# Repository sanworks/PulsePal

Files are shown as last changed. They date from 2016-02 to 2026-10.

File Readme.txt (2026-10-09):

This is the Sanworks Pulse Pal repository, maintained by Sanworks LLC.

It is an improved version of the original Pulse Pal project:
https://www.frontiersin.org/journals/neuroengineering/articles/10.3389/fneng.2014.00043/full

Pulse Pal is an open source instrument, released into the public domain under the GNU public license version 3 (see LICENSE.txt).

IMPORTANT: This license means that you can build and modify the device for your own use and even release derivative works commercially, but all derivative versions of the software and hardware MUST remain open source under the GNU public license v3.

This repository contains:
-Firmware (written in Arduino)
-Software APIs in MATLAB, Python and C++
-Design files for the circuit board
-Design files for the enclosure

Documentation and bill of materials is provided online at:
https://sites.google.com/site/pulsepalwiki/

Code contributions are welcome! Please follow guidelines in CONTRIBUTING.md

Using Pulse Pal from Python or MATLAB: USING.md covers the device limits, the standard calls, recipes for common
experiments and pitfalls.

Developer documentation: AGENTS.md is the guide to this repository (for people and for AI coding agents),
and Firmware/PROTOCOL.md documents the USB serial protocol.

Preassembled Pulse Pals are available at:
https://sanworks.io

The online documentation contains:

-Ordering and assembly guide
-Installation guide
-Programming guides
-Parameter guide
-Serial interface documentation

Please contact us with any questions, bugs, and general feedback:
admin@sanworks.io

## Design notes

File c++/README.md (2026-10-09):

# Pulse Pal C++ class

A C++ interface for Pulse Pal 2 and Pulse Pal 3, running firmware v21 or v22, on Windows, macOS and Linux.

```cpp
#include "PulsePal.h"

PulsePal pulsePal;
if (!pulsePal.initialize("COM3")) {  // "/dev/cu.usbmodem14101" on macOS, "/dev/ttyACM0" on Linux
    return 1;
}
pulsePal.setPhase1Voltage(1, 5);       // 5V pulses on output channel 1
pulsePal.setPulseTrainDuration(1, 2);  // for 2 seconds
pulsePal.triggerChannel(1);
pulsePal.end();
```

[PulsePal.h](PulsePal.h) documents every method. [PulsePalExample.cpp](PulsePalExample.cpp) is a longer
example, and the serial protocol is described in [/Firmware/PROTOCOL.md](../Firmware/PROTOCOL.md).

The class uses [libserialport](https://sigrok.org/wiki/Libserialport) for the USB serial port. It is an actively
maintained, cross-platform C library from the sigrok project, packaged for Homebrew, Debian/Ubuntu, MSYS2 and
vcpkg, and licensed LGPL-3.0-or-later. The previous version of this class, built on openFrameworks' `ofSerial`, is
in [legacy/](legacy/). Use it for Pulse Pal 1.

## Building

You need CMake 3.14 or newer and a C++11 compiler. The build makes a static library, `pulsepal`, the example
program `PulsePalExample`, and the offline tests `test_protocol`.

### Windows 11

Install Visual Studio 2022 with the "Desktop development with C++" workload, which includes CMake and the Windows
SDK. Then, in a Developer PowerShell, from this folder:

```bash
cmake -S . -B build
cmake --build build --config Release
build\Release\PulsePalExample.exe COM3
```

The first `cmake` downloads libserialport 0.1.2 from sigrok.org, checks its SHA-256 hash, and builds it with the
project, so there is nothing else to install. (Or open this folder in Visual Studio with File > Open > Folder.)

Pulse Pal's port is listed in Device Manager under "Ports (COM & LPT)".

### macOS

```bash
brew install cmake pkg-config libserialport
cmake -S . -B build
cmake --build build
./build/PulsePalExample /dev/cu.usbmodem14101
```

Pulse Pal appears as `/dev/cu.usbmodem*`. List the candidates with `ls /dev/cu.usbmodem*`. Use the `cu.` device,
not `tty.`.

### Ubuntu

```bash
sudo apt install build-essential cmake pkg-config libserialport-dev
cmake -S . -B build
cmake --build build
./build/PulsePalExample /dev/ttyACM0
```

Pulse Pal appears as `/dev/ttyACM*`. To open it without `sudo`, add yourself to the `dialout` group once, then log
out and back in:

```bash
sudo usermod -aG dialout $USER
```

## Using the class in your project

With CMake, add this folder and link to `pulsepal`:

```cmake
add_subdirectory(path/to/PulsePal/c++ pulsepal)
target_link_libraries(your_app PRIVATE pulsepal)
```

Without CMake, compile `PulsePal.cpp` and `SerialPort.cpp` with your program, and link to libserialport. Only
`SerialPort.cpp` includes `libserialport.h`.

## Errors

Methods that send a command return `true` if it was sent and, for commands the device confirms, the device
confirmed it. They return `false`, and print the reason to `std::cerr`, if:

- the device is not connected,
- an argument is out of range for the connected device, in which case nothing is sent,
- or the device rejected the command, or did not reply within 2 seconds.

A device that stops replying is usually showing **COMM. FAILURE!** on its screen, after a command was cut short (a
faulty cable or hub, or a program that stopped mid-command). Click its joystick, and call `initialize()` again.

## Pulse Pal 3

- Custom pulse trains 1-4, with up to 10,000 pulses each (Pulse Pal 2: trains 1-2, 5,000 pulses).
- Param sync trigger mode: `setTriggerMode(channel, 3)`. While a trigger channel is in this mode,
  `syncAllParams()` stores the parameters on the device, and the next rising edge on that trigger channel applies
  them. This is how the next trial's parameters can be sent during the current trial. Only `syncAllParams()` is
  held back: every other method takes effect at once. See "Param sync mode" in
  [/Firmware/PROTOCOL.md](../Firmware/PROTOCOL.md).
- `getHardwareVersion()` returns 2 or 3.

## Changes from the legacy class

The methods and fields are the same as in [legacy/PulsePal.h](legacy/PulsePal.h), plus `getHardwareVersion()`.
These changed:

- Pulse Pal 1, and firmware older than v21, are not supported. Use the legacy class.
- Methods that sent a command now return `bool` instead of `void` (see [Errors](#errors)). `initialize()` also
  returns `bool`.
- `initialize()` now programs the device with the default parameters, as the MATLAB and Python classes do, so
  that the device and `currentOutputParams` agree.
- Out-of-range values are rejected, instead of silently limited. Voltages are -10 to 10 V. Times are 0 to
  9999.9999 s, the longest time the device's joystick menu shows, except phase durations, the inter-pulse interval
  and the pulse train duration, whose minimum is 0.0001 s: two timer cycles, the shortest pulse a trigger channel
  detects reliably. Custom pulse times must be multiples of 0.0001 s. These are the MATLAB and Python classes'
  limits, listed in "Value limits" in [/Firmware/PROTOCOL.md](../Firmware/PROTOCOL.md).
- Times are rounded to the nearest 50 µs timer cycle, and voltages to the nearest DAC code, as in the Python
  class. The legacy class truncated times, so e.g. a 0.0007 s phase was sent as 13 cycles (0.00065 s) instead of 14.
- The device's confirm bytes are read. The legacy class left them unread.
- Fixed: `setInterPulseInterval()` stored its value in `interPhaseInterval`; `currentInputParams` (the trigger
  modes) was uninitialized, so `syncAllParams()` could send any trigger mode; `setPulseTrainDelay()` could not set
  a delay of 0.
- `stdafx.h` and the Visual Studio `_tmain` entry point are no longer needed.

## Tests

`tests/test_protocol.cpp` checks the bytes the class sends, using a fake serial port, so it needs no Pulse Pal. It
compares the parameter messages (ops 92 and 73) with those sent by the Python class, byte for byte. Run it after
building:

```bash
ctest --test-dir build -C Release --output-on-failure
```

(`--test-dir` needs CMake 3.20. On older versions, run `ctest -C Release` from the `build` folder.)

Everything else needs a device. `PulsePalExample` calls every method on a connected Pulse Pal, and plays pulse
trains of up to ±10 V on all four output channels, so disconnect anything attached to the outputs first.

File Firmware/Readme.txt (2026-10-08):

This folder contains the Pulse Pal firmware. To load it onto a device you can either compile it
yourself with Arduino (https://www.arduino.cc/en/software/#ide), or use a firmware loader that
needs no Arduino setup.

Loading firmware without Arduino:

1. With Python: the firmware loader for all Sanworks devices, including Pulse Pal, at
   https://github.com/sanworks/Sanworks-FirmwareLoader
2. With MATLAB: the firmware loading tool in /MATLAB/FirmwareLoader/

Compiling it yourself: the board support and libraries must be installed first. They are listed
at the top of PulsePal3/PulsePal3.ino, and in the "Building" section of PulsePal3/AGENTS.md.

Folders and files:

/PulsePal3
The current firmware. It compiles for both Pulse Pal 2 (Arduino Due) and Pulse Pal 3 (Teensy 4.1),
selected with the HARDWARE_VERSION macro at the top of PulsePal3.ino. AGENTS.md in that folder has
the code map, build instructions and the rules to follow when changing the firmware.

/WavePal
Wave Pal: alternative firmware for Pulse Pal 3 (Teensy 4.1) that makes it a four channel waveform
player. Each output channel plays a waveform of up to 1 million samples, stored on the microSD card,
when it is triggered by TTL, by software or from the joystick. It is controlled with the Python class
pulsepal.WavePalDevice (/Python/PulsePal/pulsepal/wave_pal.py) or the MATLAB class in /MATLAB/@WavePalDevice.
PROTOCOL.md and AGENTS.md in that folder describe its USB protocol and code.

/SynthPal
Synth Pal: alternative firmware for Pulse Pal 3 (Teensy 4.1) that makes it a four channel waveform
synthesizer. Each output channel plays a sine, triangle, square or sawtooth wave, or steps to a fixed
voltage, with its own levels, play duration and ramps, when it is triggered by TTL, by software or
from the joystick. One frequency, 1 Hz to 20 kHz, applies to all four. It is controlled with the
Python class pulsepal.SynthPalDevice (/Python/PulsePal/pulsepal/synth_pal.py) or the MATLAB class in
/MATLAB/@SynthPalDevice.
PROTOCOL.md and AGENTS.md in that folder describe its USB protocol and code.

/Old
Archived firmware for earlier hardware and releases, kept for reference and no longer developed.

/tools
build_check.py compiles the firmware for both hardware versions, or Wave Pal or Synth Pal (--sketch).
It can also compare the compiled code with another git revision, function by function, to confirm that
an edit did not change behavior.

PROTOCOL.md
The USB serial protocol between the device and its Python, MATLAB and C++ clients: op codes,
parameter codes, replies and the settings file layout.

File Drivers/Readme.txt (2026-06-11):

Drivers are necessary only for Windows 7 and Windows XP.
If you are using a modern operating system, you can safely ignore this folder.

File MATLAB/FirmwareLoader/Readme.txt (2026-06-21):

**MATLAB Firmware Loader for Pulse Pal**

Usage:
1. Add this folder to the MATLAB path
2. At the MATLAB command prompt, run LoadPulsePalFirmware;

Firmware files in this folder begin with stable versions as of 1 July, 2026, and include more recent updates.
If you need an earlier firmware version, it must be installed manually. Installation instructions are here:
https://sites.google.com/site/pulsepalwiki/upgrading-firmware

Note: If Python is available on your system, a unified firmware loader for all Sanworks devices is provided at https://github.com/sanworks/Sanworks-FirmwareLoader

**Credits**
Note: Firmware updating for Pulse Pal v3 / Teensy 4.1  is powered by tycmd, an open source firmware loader application for Teensy.
More details at: https://github.com/Koromix/tytools

For Pulse Pal v2 / Arduino Due, firmware updating is powered by bossac.
More details at: https://github.com/shumatech/BOSSA

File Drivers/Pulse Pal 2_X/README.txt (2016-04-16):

The driver files in this folder are open source, and part of the Arduino program:

http://www.arduino.cc/

We supply these drivers for convenience, but we reccommend downloading the latest drivers from here:
https://www.arduino.cc/en/Guide/ArduinoDue#toc8

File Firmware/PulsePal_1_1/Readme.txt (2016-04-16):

Firmware Upload Instructions

The Pulse Pal firmware can be uploaded to Pulse Pal 1 device using Leaflabs Maple software.

1. Download Maple from:
http://docs.leaflabs.com/docs.leaflabs.com/index.html
and install it on your system. 

On Windows Vista, 7, 8 and 10, you will need to install the driver from here:
https://github.com/rogerclarkmelbourne/Arduino_STM32/tree/master/drivers/win

2. Launch Maple

3. Select: File > Open and choose /PulsePal/Firmware/PulsePal_X_X/PulsePal_X_X.pde

4. Select Tools > Board > Leaflabs Maple r3+ To Flash

5. Select Tools > Port > (whichever port appears when you connect Pulse Pal, and disappears when it is disconnected)

6. Press "Upload" - the right-pointing arrow in the square button, in the first toolbar above the code

If you get stuck at "Searching for DFU Device..."DFU Device not found", try plugging in Pulse Pal the moment it says "Searching for DFU Device". 

If all goes well, after a few seconds you should see some text in the black console window that says "Verify successful".

If you have trouble uploading the firmware, please post in the Sanworks support forum:
https://sanworks.io/forum/forumdisplay.php?fid=3

These instructions are also available on the Pulse Pal Wiki at:
https://sites.google.com/site/pulsepalwiki/updating-firmware

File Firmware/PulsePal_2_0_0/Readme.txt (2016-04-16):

Firmware Upload Instructions

The Pulse Pal firmware can be uploaded to the Pulse Pal 2 device using Arduino software.
These instructions walk you through uploading with Arduino 1.6.8.

1. Download Arduino from:
https://www.arduino.cc/en/Main/Software
and install it on your system

2. Launch Arduino

3. Select: Tools > Board > Boards Manager

4. Under "Arduino SAM Boards (32-bits ARM Cortex-M3) choose "Install"

5. Close the boards Manager.

6. Select: File > Open and choose /PulsePal/Firmware/PulsePal_2_X_X/PulsePal2_X_X.ino

7. Select Tools > Board > Arduino Due (Native USB Port)

8. Select Tools > Port > (whichever port appears when you connect Pulse Pal, and disappears when it is disconnected)

9. Press "Upload" - the right-pointing arrow below in the first toolbar above the code

If all goes well, after a few seconds you should see some orange text in the black console window that says "Verify successful.... CPU reset.".

If you have trouble uploading the firmware, please post in the Sanworks support forum:
https://sanworks.io/forum/forumdisplay.php?fid=3

These instructions are also available on the Pulse Pal Wiki at:
https://sites.google.com/site/pulsepalwiki/updating-firmware

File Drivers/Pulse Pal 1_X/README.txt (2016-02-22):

This driver package for maple was published as part of the open source Arduino_STM32 repository by Roger Clark.
It was inherited in its entirety to provide simple Windows 7, 8 and 8.1 support for Pulse Pal.
To install the drivers, run /PulsePal/drivers/install_drivers.bat.

See more here:
https://github.com/rogerclarkmelbourne

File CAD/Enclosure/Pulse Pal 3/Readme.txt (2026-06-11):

Manufacturing Notes

1. The Laser cut file is for 1.5mm acrylic. Lines under 0.05mm are to be vector cut, and anything larger is to be raster engraved or printed with UV ink.

2. Tolerances in the Pulse Pal 3 Body and Wing parts are optimized for production with Multijet Fusion / PA11.

3. Tolerances in the ScreenMount part are optimized for production by FDM with Prusa Core One / PETG.

4. Attach the laser-cut front panel to the 3D printed body using VHB tape on BOM.

5. Press square nuts (4) into square nut pockets on Pulse Pal 3 Body.

6. Use small sections of VHB Tape to seal square nuts into square nut pockets. They are a friction fit but may become loose on impact.

7. Silver thread-forming screws secure Pulse Pal board into enclosure (3) and laser-cut panel to rear of enclosure (4).

8. Black machine screws (2) secure wing to body.

9. Press light pipes into light pipe sockets on Pulse Pal 3 Body. The final section of the light pipe should press into place with significant resistance. Hammer gently with a rubber mallet if they cannot be pressed by hand (ensuring that all electronics and acrylic panels are removed from the body while hammering).

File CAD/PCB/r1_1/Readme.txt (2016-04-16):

----------------------------------------------------------------------------

The files in this folder are part of the Sanworks Pulse Pal repository
Copyright (C) 2016 Sanworks LLC, Sound Beach, New York, USA

----------------------------------------------------------------------------

These design files are free software: you can redistribute and/or modify
them under the terms of the GNU General Public License as published by
the Free Software Foundation, version 3.

These files are distributed  WITHOUT ANY WARRANTY and without even the 
implied warranty of MERCHANTABILITY or FITNESS FOR A PARTICULAR PURPOSE.  
See the GNU General Public License for more details.

You should have received a copy of the GNU General Public License
along with these files. If not, see <http://www.gnu.org/licenses/>.

-----------------------------------------------------------------------------

*Instructions*

The schematic Rev_X.X.sch,
and the circuit board design file Rev_X.X.brd,
can be opened with Cadsoft Eagle:
http://www.cadsoftusa.com/

The GERBER files are pre-compiled CAM files for circuit board manufacturing with SeeedStudio's fusion PCB service.
USA: http://www.seeedstudio.com/service/index.php?r=upcb
Global: http://www.seeedstudio.com/service/index.php?r=pcb

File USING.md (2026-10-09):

# Using Pulse Pal

This guide is for writing experiment code with a Pulse Pal, and with Wave Pal and Synth Pal, the
alternative firmwares for Pulse Pal 3. It covers the device's limits, the standard calls in
Python and MATLAB, recipes for common experiments, and the mistakes that are easy to make. It is
written for scientists and for AI agents that help them. To change this repository instead (the
firmware, the classes, the protocol), see `AGENTS.md`.

The full API reference is in each class: the [Python documentation](https://sanworks.github.io/PulsePal/Python/),
or `help PulsePalDevice` (and `help WavePalDevice`, `help SynthPalDevice`) in MATLAB, which
starts with an example. Python has example scripts: `/Python/PulsePal/PulsePalExample.py`,
`WavePalExample.py` and `SynthPalExample.py`.

## Which firmware

| Firmware | Plays | Hardware | Class (Python and MATLAB) |
|---|---|---|---|
| Pulse Pal | Pulse trains: monophasic or biphasic pulses, bursts, and custom trains of up to 10000 pulses | Pulse Pal 2 and 3 | `PulsePalDevice` |
| Wave Pal | One sampled waveform per channel, up to 1 million samples at up to 100 kHz | Pulse Pal 3 | `WavePalDevice` |
| Synth Pal | Sine, triangle, square and sawtooth waves, white noise, and fixed voltages, 1 Hz to 20 kHz, with on and off ramps | Pulse Pal 3 | `SynthPalDevice` |

A Pulse Pal 3 runs one firmware at a time. To change it, run `LoadPulsePalFirmware` in MATLAB
(add `/MATLAB/FirmwareLoader` to the path first). Connecting with the wrong class raises an error
that names the firmware the device runs. A class connects to firmware newer than it knows, with a
warning: new firmware only adds commands, so the class works as before. Update the classes to use
what is new.

## Before an experiment

1. **Install.** Python: run `uv sync` in `/Python/PulsePal` (see its `README.md`), and
   `from pulsepal import PulsePalDevice`. MATLAB R2020b or newer: add `/MATLAB` to the path.
2. **Find the port.** `PulsePalDevice.serialportlist()` in Python, `serialportlist` in MATLAB.
   If several are listed, unplug the device and see which one disappears. Only one program at a
   time can have the port open.
3. **Check what the outputs drive.** The outputs swing from -10 V to +10 V. Keep every voltage
   within what the connected equipment accepts: a laser or LED driver that takes 0-5 V can be
   damaged by a voltage the Pulse Pal plays without complaint.
4. **Trigger inputs take TTL:** 0 V low, 3 to 5 V high. A trigger channel reads its input once
   every 50 µs, so a trigger pulse must last at least 100 µs to be seen reliably.
5. **Connecting programs the defaults.** Whatever the device held (a program set with its
   joystick, or by an earlier script) is replaced. To keep a program, save it to a settings
   file on the device and load it after connecting (see "Run without a computer" below).
6. **Closing stops the outputs**, on all three firmwares: `P.close()`, the end of a `with`
   block, or the object being garbage collected in Python; `clear P` or `delete(P)` in MATLAB.
   Keep the object for as long as the outputs should play. The settings stay on the device, so
   TTL triggers still play them after the connection closes.

## How the classes work

The six classes (three firmwares, two languages) work the same way, with snake_case names in
Python and camelCase in MATLAB.

- **Settings are per channel.** Each is a property with one value per output channel: in
  Python a list indexed by channel number, where index 0 is unused and holds `None`; in MATLAB
  a 1x4 array, or a 1x4 cell array for names. `trigger_mode` / `triggerMode` has one value per
  trigger channel (1 and 2).
- **Address channels.** Set one channel by its number, or all of them with one value per
  channel. A single value for a whole setting (`P.phase1_voltage = 5`) raises an error, because
  it does not say which channels it is meant for.
- **Assigning a setting programs the device at once.** To send several changes in one command,
  use a `batch()` block in Python, or turn `autoSync` off in MATLAB and call `syncToDevice()`.
- **Modes are names** (`"Gated"`, `"Sine"`; not case sensitive), and on/off settings are
  `True`/`False` (`true`/`false`).
- **Values are checked before anything is sent.** A value the device cannot play raises an
  error (`pulsepal.PulsePalError` in Python), and the device keeps its previous settings.
- **`trigger(channels)` and `stop(channels)`** take one channel number, or several as a list,
  tuple or NumPy array in Python, or an array in MATLAB. `stop()` with no argument stops all.
- **`print(P)`** in Python, or `P` at the MATLAB prompt, shows every setting.

```python
from pulsepal import PulsePalDevice

P = PulsePalDevice("COM3")
P.phase1_voltage[2] = 5                 # channel 2 only
P.phase1_duration = [0.001] * 4         # all four channels
with P.batch():                         # several changes, sent together at the end
    P.phase1_voltage[1] = 2.5
    P.inter_pulse_interval[1] = 0.02
P.trigger([1, 2])
```

```matlab
P = PulsePalDevice('COM3');
P.phase1Voltage(2) = 5;                 % channel 2 only
P.phase1Duration(:) = 0.001;            % all four channels
P.autoSync = false;                     % several changes, sent together
P.phase1Voltage(1) = 2.5;
P.interPulseInterval(1) = 0.02;
P.syncToDevice();
P.autoSync = true;
P.trigger([1 2]);
```

## Pulse Pal

### Limits

| | |
|---|---|
| Output channels | 4, -10 V to +10 V |
| Voltage steps | 0.305 mV on Pulse Pal 3 (16-bit DAC); 4.88 mV on Pulse Pal 2 (12-bit DAC, which plays the step at or below the voltage) |
| Time steps | 50 µs: every time is rounded to the nearest 50 µs, and the property then holds the rounded time (0.00012 reads back as 0.0001) |
| Longest time | 9999.9999 s, for every time setting and custom pulse time |
| Shortest pulse | 100 µs, for the phase durations, the inter-pulse interval and the pulse train duration: the shortest pulse another Pulse Pal's trigger input detects reliably |
| Custom trains | Pulse Pal 3: 4 trains of up to 10000 pulses. Pulse Pal 2: 2 trains of up to 5000. Pulse times are multiples of 100 µs |
| Trigger channels | 2, TTL. Measured on a Pulse Pal 3, an output starts 58 to 108 µs after a trigger's rising edge, depending on where the edge falls in the device's 50 µs cycle |
| Soft triggers | `trigger()` reaches the device over USB, which adds a variable delay. The channels it names start together, in the same 50 µs cycle |

### Pulse Pal 2 and Pulse Pal 3

| | Pulse Pal 2 | Pulse Pal 3 |
|---|---|---|
| Processor | Arduino Due | Teensy 4.1 |
| DAC | 12-bit, 4.88 mV steps | 16-bit, 0.305 mV steps |
| Custom trains | 2, of up to 5000 pulses | 4, of up to 10000 pulses |
| Param sync trigger mode | No | Yes |
| Settings files on the microSD card | Yes | Yes, and `format_microsd()` |
| Screen saver, zero-code calibration | No | Yes |
| Wave Pal and Synth Pal firmware | No | Yes |

`P.info` holds the connected device's hardware and firmware versions and its limits
(`info.hardware_version`, `info.n_custom_pulse_trains`, `info.max_custom_pulses`, ...). Some
features need firmware v22, the current version: continuous loop mode, stopping some channels
only, reading the parameters back, and param sync.

### Parameters

A trigger starts a pulse train on each output channel it reaches. The train waits
`pulse_train_delay`, then plays pulses for `pulse_train_duration`:

```
trigger
 |-- delay --|----------------------------- pulse_train_duration ------------------------------|
             |phase 1|---- inter_pulse_interval ----|phase 1|---- inter_pulse_interval ----|...
biphasic:    |phase 1|ipi|phase 2|-- inter_pulse_interval --|phase 1|ipi|phase 2|-- ...
             (ipi: inter_phase_interval)
```

| Python | MATLAB | Meaning | Default |
|---|---|---|---|
| `phase1_voltage` | `phase1Voltage` | Voltage of each pulse's first phase | 5 V |
| `phase1_duration` | `phase1Duration` | Duration of the first phase | 1 ms |
| `inter_pulse_interval` | `interPulseInterval` | From the **end** of one pulse to the start of the next | 10 ms |
| `pulse_train_duration` | `pulseTrainDuration` | Duration of the train | 1 s |
| `pulse_train_delay` | `pulseTrainDelay` | From the trigger to the first pulse | 0 |
| `resting_voltage` | `restingVoltage` | Voltage between pulses, and while the channel is idle | 0 V |
| `is_biphasic` | `isBiphasic` | `True`: each pulse has a second phase | `False` |
| `inter_phase_interval` | `interPhaseInterval` | Rest between the two phases (biphasic only) | 1 ms |
| `phase2_voltage`, `phase2_duration` | `phase2Voltage`, `phase2Duration` | The second phase (biphasic only) | -5 V, 1 ms |
| `burst_duration` | `burstDuration` | Pulses play in bursts of this length. 0: no bursts | 0 |
| `inter_burst_interval` | `interBurstInterval` | Rest between bursts | 0 |
| `link_trigger_channel1`, `link_trigger_channel2` | `linkTriggerChannel1`, `linkTriggerChannel2` | Whether trigger channel 1 (or 2) starts this output channel | channel 1: `True`; channel 2: `False` |
| `custom_train_id` | `customTrainID` | 0: the train above. 1-4: a custom train (see below) | 0 |
| `custom_train_target` | `customTrainTarget` | `"Pulses"`: custom times are pulse onsets. `"Bursts"`: they are burst onsets | `"Pulses"` |
| `custom_train_loop` | `customTrainLoop` | `True`: repeat the custom train until the train duration ends | `False` |
| `continuous_loop` | `continuousLoop` | `True`: play until stopped, ignoring the train duration | `False` |
| `trigger_mode` | `triggerMode` | Per trigger channel, see "Trigger modes" | `"Normal"` |

A monophasic train plays one pulse every `phase1_duration + inter_pulse_interval` seconds. A
biphasic train plays one every `phase1_duration + inter_phase_interval + phase2_duration +
inter_pulse_interval` seconds.

### Standard calls

| Python | MATLAB | Does |
|---|---|---|
| `P = PulsePalDevice("COM3")` | `P = PulsePalDevice('COM3');` | Connects, and programs the defaults |
| `P.trigger([1, 3])` | `P.trigger([1 3]);` | Starts the channels' trains (from the computer) |
| `P.stop()`, `P.stop(2)` | `P.stop();`, `P.stop(2);` | Stops all channels, or some. They return to their resting voltage |
| `P.set_fixed_voltage(4, 2.5)` | `P.setFixedVoltage(4, 2.5);` | Holds channels at a voltage until they are triggered |
| `with P.batch(): ...` | `P.autoSync = false; ... P.syncToDevice();` | Sends several changes in one command |
| `P.send_custom_pulse_train(1, times, volts)` | `P.sendCustomPulseTrain(1, times, volts);` | Loads custom train 1: pulse onset times and voltages |
| `P.send_custom_waveform(1, period, volts)` | `P.sendCustomWaveform(1, period, volts);` | Loads a sampled waveform as custom train 1 |
| `P.export_params()` | `P.exportParams()` | Every parameter, as a dict or struct, e.g. to save with your data |
| `P.import_params(params)` | `P.importParams(params);` | Programs the parameters `export_params()` returned |
| `P.sync_from_device()` | `P.syncFromDevice();` | Reads the device's parameters into the object, e.g. after using the joystick |
| `P.set_default_params()` | `P.setDefaultParams();` | Programs the defaults |
| `P.save_settings_file("A.pps")` | `P.saveSettingsFile('A.pps');` | Saves the parameters to the microSD card; also `load_settings_file`, `delete_settings_file` |
| `P.set_screen_saver(True, 300)` | `P.setScreenSaver(true, 300);` | Dims the screen after 300 s without activity (Pulse Pal 3). Kept on the device |
| `P.gui()` | `P.gui();` | Opens the parameter editor window |
| `P.close()` | `clear P` | Disconnects, and stops all outputs |

### Trigger modes

Each trigger channel starts the output channels linked to it (`link_trigger_channel1`,
`link_trigger_channel2`), in one of these modes:

| Mode | A TTL rising edge... |
|---|---|
| `"Normal"` | starts the linked channels' trains. Edges during a train are ignored |
| `"Toggle"` | starts the trains, and an edge during a train stops it |
| `"Gated"` | starts the trains, and the falling edge stops them: they play while the TTL is high. A channel linked to both trigger channels, both gated, plays until both are low |
| `"Param Sync"` | starts nothing: it loads the parameters most recently sent with `sync_to_device()` (Pulse Pal 3 only; see the recipe below) |

### Recipes

**A pulse train on each trial's TTL.** For example 20 Hz, 5 ms pulses for 1 s, started by a TTL
from the behavior system on trigger channel 1:

```python
P = PulsePalDevice("COM3")
P.phase1_voltage[1] = 5               # V
P.phase1_duration[1] = 0.005          # 5 ms pulses
P.inter_pulse_interval[1] = 0.045     # 45 ms from the end of one pulse to the next: 20 Hz
P.pulse_train_duration[1] = 1         # 20 pulses
P.link_trigger_channel1[1] = True     # the default
P.trigger_mode[1] = "Normal"          # the default: TTLs during the train are ignored
```

```matlab
P = PulsePalDevice('COM3');
P.phase1Voltage(1) = 5;
P.phase1Duration(1) = 0.005;
P.interPulseInterval(1) = 0.045;
P.pulseTrainDuration(1) = 1;
```

**Play while a TTL is high.** Gated mode stops the train at the TTL's falling edge, and
continuous loop mode keeps it going until then, however long the TTL lasts:

```python
P.trigger_mode[1] = "Gated"
P.continuous_loop[1] = True
```

**Trial-by-trial parameters with param sync (Pulse Pal 3).** Each trial's parameters are sent
during the trial before, and applied at the instant the next one starts. Wire the trial-start
TTL to **both** trigger channels: trigger channel 2, in param sync mode, loads the stored
parameters, and trigger channel 1 starts the train in the same 50 µs cycle, with the new
parameters.

```python
P = PulsePalDevice("COM3")
P.link_trigger_channel1[1] = True     # trigger channel 1 starts output channel 1
P.trigger_mode[2] = "Param Sync"      # sent at once
for voltage in [2.5, 5, 7.5]:
    with P.batch():                   # stored by the device, not applied
        P.phase1_voltage[1] = voltage
    wait_for_end_of_trial()           # your code. The next TTL loads the stored set and starts the train
P.trigger_mode[2] = "Normal"          # leaving param sync mode: assigned outside a batch, so sent at once
```

```matlab
P.triggerMode{2} = 'Param Sync';
for voltage = [2.5 5 7.5]
    P.autoSync = false;
    P.phase1Voltage(1) = voltage;
    P.syncToDevice();                 % Stored for the next TTL on trigger channel 2
    P.autoSync = true;
    waitForEndOfTrial();
end
P.triggerMode{2} = 'Normal';
```

Make each train end before the next trial's TTL: a channel still playing at the edge finishes
its train on the old parameters, and ignores the start trigger on channel 1, so the new trial's
train would not play.

**Charge-balanced biphasic pulses.** 200 µs at +3 V, 100 µs gap, 200 µs at -3 V, 100 times a
second for 2 s:

```python
with P.batch():
    P.is_biphasic[1] = True
    P.phase1_voltage[1] = 3
    P.phase1_duration[1] = 0.0002
    P.inter_phase_interval[1] = 0.0001
    P.phase2_voltage[1] = -3
    P.phase2_duration[1] = 0.0002
    P.inter_pulse_interval[1] = 0.0095   # 0.2 + 0.1 + 0.2 + 9.5 ms = a 10 ms period
    P.pulse_train_duration[1] = 2
```

**Custom pulse trains and waveforms.** A custom train sets each pulse's onset time and voltage;
its pulse width is the channel's `phase1_duration`. A custom waveform is a custom train of
adjoining pulses, one per sample:

```python
P.send_custom_pulse_train(1, [0, 0.1, 0.15, 0.5], [5, 5, 2.5, 5])  # times in multiples of 100 us
P.custom_train_id[2] = 1
P.phase1_duration[2] = 0.002

import numpy as np
samples = 4 * np.sin(2 * np.pi * 10 * np.arange(1000) / 1000)    # 1 s of a 10 Hz sine, at 1 kHz
P.send_custom_waveform(2, 0.001, samples)
P.custom_train_id[3] = 2
P.phase1_duration[3] = 0.001          # each sample lasts the whole sampling period
```

A Pulse Pal 3 holds 10000 samples per train, so a custom waveform lasts at most 1 s at 10 kHz.
For longer or faster waveforms, use Wave Pal.

**Record exactly what was played.** `export_params()` returns every parameter as the device
plays it (times rounded to 50 µs), in a form `json` can save:

```python
import json
with open("session_params.json", "w") as f:
    json.dump(P.export_params(), f)
```

In MATLAB, `P.saveParameters('session.json')` saves them as a program file (below), or
`params = P.exportParams(); save('session.mat', 'params')`.

**Program files.** The Python and MATLAB GUIs save and open the same `.json` program files, and
MATLAB's `saveParameters()` and `loadParameters()` write and read them too. A program file holds
`format_version` (1), `params` (what `export_params()` returns: Python's snake_case names, mode
names, `true` and `false`), the text of each custom train as typed in a GUI, and `device_info`.
To program a device from one in Python:

```python
import json
with open("MyProgram.json") as f:
    P.import_params(json.load(f)["params"])
```

In MATLAB, `P.loadParameters('MyProgram.json')`. A GUI's custom trains are loaded only by
opening the file in a GUI. `import_params()`, `importParams()` and `loadParameters()` skip names
they do not know, with a warning, and the GUIs ignore them, so a file saved by a newer version
still loads.

**Run without a computer.** Save a program to the device's microSD card, then load it from the
joystick menu (or with `load_settings_file()`):

```python
P.save_settings_file("OPTO20HZ.pps")  # at most 11 characters, then .pps
```

### Pitfalls

- **The inter-pulse interval is not the period.** It runs from the end of one pulse to the
  start of the next. 5 ms pulses at 20 Hz need an inter-pulse interval of 45 ms, not 50 ms.
- **Times round to 50 µs.** 0.00012 s plays as 0.0001 s, and 125 µs (2.5 steps) as 100 µs.
  Read the property back to see what the device plays.
- **The end of a train can cut pulses.** A monophasic pulse still playing when the train ends
  is cut short. A biphasic pulse starts only if it can finish before the train ends, and in
  bursts, a pulse starts only if it fits in the burst, so the last pulse may be missing.
- **Changes reach a playing train at once.** A parameter changed while a train plays changes
  that train mid-way. Only param sync waits for the next trial.
- **A channel that is playing ignores a new trigger,** soft or TTL in normal mode, and so does
  one waiting out its pulse train delay. Stop it first, or let the train end.
- **Connecting replaces the device's program** with the defaults, and a program set with the
  joystick afterwards is not in the object until `sync_from_device()` reads it.
- **In param sync mode, only `sync_to_device()` waits for the TTL** (including the end of a
  `batch()` block). An assignment with `auto_sync` on programs the device at once. The param
  sync channel itself starts nothing.
- **Custom trains.** A custom train that does not loop plays all its pulses and ends, whatever
  the train duration; one that loops stops at the train duration. Custom pulse times must be
  multiples of 100 µs: a time in between raises an error rather than being rounded. A train
  targeting bursts (`custom_train_target` `"Bursts"`) needs a burst duration.
- **Continuous loop mode is not saved** in settings files, and is not read back by
  `sync_from_device()`.
- **A non-zero resting voltage is output all the time** the channel is idle, from the moment
  it is set.
- **Unplugging the USB cable during playback** stops it: the device shows "COMM. FAILURE!",
  returns the outputs to their resting voltages, and loads its default parameters.

## Wave Pal

Wave Pal plays one sampled waveform per output channel, stored on the device's microSD card.

### Limits

| | |
|---|---|
| Waveform length | 1 to 1,000,000 samples per channel |
| Sampling rate | 1 Hz to 100 kHz, one rate for all four channels. The device divides a 24 MHz clock by a whole number, so the rate played (`actual_sampling_rate`) can differ slightly: 44100 Hz plays at 44117.6 Hz. Rates that divide 24 MHz, such as 10, 25 or 100 kHz, play exactly |
| Output ranges | `"0V:5V"`, `"0V:10V"`, `"-5V:5V"`, `"-10V:10V"`, one for all channels. The smallest range that fits the waveforms gives the finest voltage steps |
| Trigger modes | `"Normal"`, `"Toggle"`, `"Gated"`, as in Pulse Pal, and `"Master"`: a rising edge restarts channels that are playing. No param sync |

### Standard calls

| Python | MATLAB | Does |
|---|---|---|
| `W = WavePalDevice("COM3")` | `W = WavePalDevice('COM3');` | Connects, stops playback, programs the defaults (10 kHz, -10 V to 10 V) |
| `W.sampling_rate = 50000` | `W.samplingRate = 50000;` | Sets the sampling rate, Hz |
| `W.output_range = "-5V:5V"` | `W.outputRange = '-5V:5V';` | Sets the output range |
| `W.load_waveform(1, volts)` | `W.loadWaveform(1, volts);` | Loads a waveform onto a channel, in volts |
| `W.loop_mode[1] = True`, `W.loop_duration[1] = 3` | `W.loopMode(1) = true; W.loopDuration(1) = 3;` | Loops the waveform, for 3 s after each trigger (0: until stopped) |
| `W.trigger([1, 2])`, `W.stop()` | `W.trigger([1 2]);`, `W.stop();` | Starts, or stops, playback |
| `W.set_fixed_voltage(3, 1.5)` | `W.setFixedVoltage(3, 1.5);` | Holds channels at a voltage |
| `W.status()` | `W.status()` | Which channels are playing, and any underruns |
| `W.export_params()` | `W.exportParams()` | Every setting, as a dict or struct, e.g. to save with your data. Not the waveforms |
| `W.set_screen_saver(True, 300)` | `W.setScreenSaver(true, 300);` | Dims the screen after 300 s without activity. Kept on the device, shared with the other firmwares |

### Recipe: a waveform on each trial's TTL

```python
import numpy as np
from pulsepal import WavePalDevice

W = WavePalDevice("COM3")
W.sampling_rate = 25000
W.output_range = "-5V:5V"                             # finer steps than -10V:10V, for a waveform within +/-5 V
t = np.arange(25000) / W.actual_sampling_rate          # 1 s
W.load_waveform(1, 3 * np.sin(2 * np.pi * 8 * t))     # an 8 Hz sine, +/-3 V
W.link_trigger_channel1[1] = True                     # the default: trigger channel 1 starts it
```

### Pitfalls

- **Stopped channels output 0 V.** Wave Pal has no resting voltage.
- **Changing the output range stops playback** and loads the waveforms again, encoded for the
  new range. A waveform that does not fit the new range raises an error.
- **Loading a waveform stops that channel.** Other channels keep playing.
- **Compute sample times from the rate the device plays,** `actual_sampling_rate`, when the
  waveform's frequency matters.
- **The object knows only the waveforms it loaded.** `status()` shows what the device holds,
  which can include waveforms from an earlier session; load them again after connecting.
- **Underruns.** Long waveforms stream from the microSD card. Check `status()` after an
  experiment: an underrun is a block of samples that arrived late, during which the output
  held its last value.
- **Gated mode** plays a waveform for exactly as long as the TTL is high only with loop mode on
  and a loop duration of 0.

## Synth Pal

Synth Pal computes each channel's waveform as it plays: a sine, triangle, square or sawtooth
wave or white noise around a mean voltage, or a step to a fixed voltage, with optional on and off
ramps.

### Limits

| | |
|---|---|
| Frequency | 1 Hz to 20 kHz in steps of 0.01 Hz, **one frequency for all four channels**. It is played exactly: the sampling rate is a whole multiple of it, up to 100 kHz |
| Levels | A periodic waveform, or white noise, swings `peak_to_peak / 2` above and below its `mean_voltage`, within -10 V to 10 V: `abs(mean_voltage) + peak_to_peak / 2 <= 10`. A `"Fixed Voltage"` channel steps to its `fixed_voltage`, -10 V to 10 V |
| White noise | `"White Noise"`: a new random voltage on every sample, uniform over `peak_to_peak` around `mean_voltage`. It is rendered at the sampling rate the frequency sets (`sampling_rate`, 50 to 100 kHz), so no claim is made about its spectrum. Each channel has its own random sequence, new on every playback; the sequences start from the same point when the device powers up |
| Durations | `play_duration` and the ramps: up to 3600 s. A play duration of 0 plays until stopped |
| Trigger modes | `"Normal"`, `"Toggle"`, `"Gated"` and `"Param Sync"`, as in Pulse Pal |

### Standard calls

| Python | MATLAB | Does |
|---|---|---|
| `S = SynthPalDevice("COM3")` | `S = SynthPalDevice('COM3');` | Connects, stops playback, programs the defaults (100 Hz sine, 5 V peak to peak, 1 s) |
| `S.frequency = 40` | `S.frequency = 40;` | Sets the frequency of all channels, Hz |
| `S.configure(1, waveform="Sine", peak_to_peak=4, mean_voltage=1)` | `S.configure(1, 'waveform', 'Sine', 'peakToPeak', 4, 'meanVoltage', 1);` | Sets several of a channel's settings, checked together |
| `S.play_duration[1] = 2` | `S.playDuration(1) = 2;` | Seconds at full amplitude after each trigger |
| `S.on_ramp_duration[1] = 0.5` | `S.onRampDuration(1) = 0.5;` | Fade-in after each trigger; `off_ramp_duration` fades out |
| `S.resting_voltage[1] = 0` | `S.restingVoltage(1) = 0;` | Output between playbacks |
| `S.trigger([1, 2])`, `S.stop()` | `S.trigger([1 2]);`, `S.stop();` | Starts, or stops (over the off ramp), playback |
| `with S.batch(): ...` | `S.autoSync = false; ... S.syncToDevice();` | Sends several changes in one command |
| `S.status()` | `S.status()` | Which channels are playing, and their output ranges |
| `S.export_params()` | `S.exportParams()` | Every setting, as a dict or struct, e.g. to save with your data |
| `S.sync_from_device()` | `S.syncFromDevice();` | Reads the device's settings into the object, e.g. after using the joystick |
| `S.set_screen_saver(True, 300)` | `S.setScreenSaver(true, 300);` | Dims the screen after 300 s without activity. Kept on the device, shared with the other firmwares |

### Recipes

**A 40 Hz sine for 30 s, faded in and out over 2 s:**

```python
from pulsepal import SynthPalDevice

S = SynthPalDevice("COM3")
S.frequency = 40
S.configure(1, waveform="Sine", peak_to_peak=2, mean_voltage=0, play_duration=30,
            on_ramp_duration=2, off_ramp_duration=2)
S.trigger(1)            # from trigger to rest: 2 + 30 + 2 = 34 s
```

**Trial-by-trial frequency with param sync.** As in Pulse Pal: trigger channel 2 in param sync
mode, the trial-start TTL wired to both trigger channels, and each trial's settings sent in a
`batch()` block during the trial before. At the edge, the frequency and the trigger modes
change at once; a channel at rest takes its new settings at once, and one still playing
finishes on its old settings (at the new frequency) and takes the new ones when it reaches its
resting voltage.

### Pitfalls

- **The frequency is shared** by all four channels.
- **Levels are checked together.** Raising `peak_to_peak` beyond what the mean voltage allows
  raises an error: change the mean voltage first, or set both in one `configure()` call.
- **`peak_to_peak` or `fixed_voltage`:** the waveform decides which one plays. A channel keeps
  both. The device holds only the one that plays, so `sync_from_device()` reads that one, and
  the object keeps its own value of the other.
- **Settings changed with the joystick** are not in the object until `sync_from_device()` reads
  them.
- **The ramps lengthen playback:** a trigger plays `on_ramp_duration + play_duration +
  off_ramp_duration`, and a stop (including closing the connection) fades out over the off
  ramp. A trigger during the off ramp fades the channel back in without restarting its cycle.
- **Gated mode** plays for exactly as long as the TTL is high (plus the off ramp) only with a
  play duration of 0.
- **Waveforms start at the trigger:** sine and triangle at the mean voltage, rising; square
  high for the first half of each cycle; sawtooth rising from its lowest voltage.
- **For white noise, the frequency sets only the sampling rate,** not a band: every sample is
  a new value. To shape its spectrum, filter the output.

## More

- `/Firmware/PROTOCOL.md`, `/Firmware/WavePal/PROTOCOL.md` and `/Firmware/SynthPal/PROTOCOL.md`
  document the USB protocols, for writing a client in another language. `/c++/` holds a C++
  class for Pulse Pal.
- The Pulse Pal wiki, https://sites.google.com/site/pulsepalwiki/, has the hardware
  documentation and a parameter guide with diagrams.

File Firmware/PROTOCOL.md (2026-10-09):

# Pulse Pal serial protocol

This is the reference for the USB serial protocol between a Pulse Pal and its client
software, as of firmware v22. It applies to Pulse Pal 2 and Pulse Pal 3 except where noted.

Four clients use this protocol, and all of them must agree with the firmware:

| Client | Location |
|---|---|
| Python class | `pulsepal.PulsePalDevice`, in `/Python/PulsePal/pulsepal/pulse_pal.py` |
| MATLAB class | `/MATLAB/@PulsePalDevice/PulsePalDevice.m` |
| MATLAB legacy functions | `/MATLAB/Legacy/` |
| C++ class | `/c++/PulsePal.cpp` |

On the device, `processUSBCommands()` in `/Firmware/PulsePal3/USBOps.ino` executes commands,
and the `OpCode` and `ParamID` enums in `/Firmware/PulsePal3/PulsePal3.ino` define the codes.

**The numbers on this page are fixed.** Installed copies of the clients use these op codes,
parameter codes and message layouts, so they must never be renumbered or reordered. New
functionality gets a new op code.

## Message format

Every command from the PC is:

```
213 (OpMenuByte), op code, op-specific data
```

- Multi-byte values are little-endian.
- Times are in hardware timer cycles of 50 µs (20000 cycles per second). Op 94 reports the
  cycle period.
- Voltages are 16-bit DAC codes: 0 is −10 V, 32768 is 0 V and 65535 is +10 V.
- Output channels are numbered 1-4 and trigger channels 1-2, except in op 96 (0-3).

## Connecting

The Python, MATLAB and C++ classes connect in this order:

1. Op 72 (handshake). The reply is `75` ('K') and the firmware version. A device running
   Wave Pal firmware (`/Firmware/WavePal`) replies `87` ('W') instead, and one running Synth
   Pal firmware (`/Firmware/SynthPal`) `83` ('S'). The Python, MATLAB and C++ classes then
   say which firmware the device runs, and that it needs Pulse Pal firmware. They refuse
   firmware older than v21, and connect to v21 with a notice that v22 is available.
   A firmware version newer than the client knows is used, with a warning: new firmware only
   adds ops, so the client's ops work as before.
   The Python, MATLAB and C++ classes discard any bytes waiting in the port before op 72: the end
   of a reply that an earlier session did not read would be taken as the handshake. That does not
   cover a command that an earlier session sent just before it closed, if the device has not
   reached it yet (it may be redrawing its screen, which takes a few ms): the device answers it
   after the discard, just before op 72. So the classes read the reply to op 72 until no byte has
   arrived for 50 ms (at most 1 s), and take the last 5 bytes. This adds about 50 ms to
   connecting.
2. Op 94, on firmware v22 and newer: hardware version, timer period, and custom train limits.
3. Op 89, to show the client's name on the device's screen (Python and MATLAB). The C++
   class leaves this to the program, which calls `setClientIDString()`.
4. On Pulse Pal 3: set both trigger modes to normal, with op 74 (Python) or op 91 (MATLAB and
   C++), so that a device left in [param sync mode](#param-sync-mode-pulse-pal-3-trigger-mode-3)
   runs the next step instead of storing it.
5. Op 92, to program the client's default parameters.

## Confirm bytes

Ops marked "1 / 0" below reply with one byte:

- **1**: the command was executed.
- **0**: the command was rejected, because a channel number, parameter code, data length or
  value was out of range for the connected device.

The MATLAB and Python classes raise an error when they receive 0, and the C++ class returns
false.

When the firmware rejects a command, it discards the command's data so that the data is not
read as the next command. If it cannot tell how long the data is (an unknown parameter
code), it discards everything received until the port has been quiet for 100 ms.

## Op codes

Ops 73, 92 and 93 carry every parameter, in this order:

- Times: phase 1 duration, inter-phase interval, phase 2 duration, inter-pulse interval,
  burst duration, burst interval, pulse train duration, pulse train delay.
- Voltages: phase 1, phase 2, resting.
- Trigger links: 4 bytes for trigger channel 1 (one per output channel 1-4), then 4 for
  trigger channel 2. Each byte is 1 if that output channel is linked to that trigger channel.

| Op | Name | Data sent after the op code | Reply |
|---|---|---|---|
| 72 | Handshake | none | `75` ('K'), then firmware version (uint32) |
| 73 | Program all parameters (legacy) | For each output channel: 8 uint32 times. Then for each output channel: 3 uint16 voltages. Then for each output channel: 4 bytes (biphasic, custom train ID, custom train target, custom train loop). Then 8 trigger link bytes, then 2 trigger mode bytes | 1 / 0 |
| 74 | Program one parameter | Parameter code, channel (1-4, or 1-2 for trigger parameters), value (1, 2 or 4 bytes, see [Parameter codes](#parameter-codes-ops-74-and-91)) | 1 / 0 |
| 75 | Load custom train 1 (legacy) | Pulse count (uint32), that many uint32 times, that many uint16 voltages | 1 / 0 |
| 76 | Load custom train 2 (legacy) | As op 75 | 1 / 0 |
| 77 | Soft-trigger channels | 1 byte, one bit per output channel (bit 0 = channel 1) | none |
| 78 | Show a message on the screen | Length byte, then that many characters. A character of 254 moves to the second line | none |
| 79 | Set a fixed voltage | Channel (1-4), DAC code (uint16) | 1 / 0 |
| 80 | Stop all channels | none | none |
| 81 | Disconnect: stop all channels and restore the device's own screen title. Wave Pal and Synth Pal firmware do the same | none | none |
| 82 | Set continuous loop mode | Channel (1-4), state (0 or 1) | 1 / 0 |
| 85 | Send the current settings file | none | 178 bytes: the file without its end marker |
| 86 | Write a pin (debugging) | Pin number, value | none |
| 87 | Read a pin (debugging) | Pin number | Pin state (1 byte) |
| 89 | Set the client name | 6 characters, shown as "NAME Connected" | none |
| 90 | Settings file operation | Operation (1 save, 2 load, 3 delete), name length, name characters | 1 / 0, after the file operation has finished |
| 91 | Program one parameter on all channels | Parameter code, then one value per output channel (4 values), or per trigger channel (2 values) for code 128 | 1 / 0 |
| 92 | Program all parameters | 182 bytes, grouped by parameter: each array holds one parameter for output channels 1-4. 8 uint32 arrays (times), 3 uint16 arrays (voltages), then byte arrays: biphasic, custom train ID, custom train target, custom train loop, continuous loop. Then 8 trigger link bytes, then 2 trigger mode bytes | 1 / 0 |
| 93 | Send all parameters | none | 178 bytes, in op 92 order without the continuous loop bytes |
| 94 | Send hardware info | none | Hardware version (byte), timer period in µs (uint32), number of custom trains (byte), maximum pulses per train (uint32) |
| 95 | Load a custom train | Train index (0 = train 1), pulse count (uint32), that many uint32 times, that many uint16 voltages | 1 / 0 |
| 96 | Set DAC calibration | Channel (0-3), zero-code offset (int16). Pulse Pal 3 keeps it through power cycles; Pulse Pal 2 does not | 1 / 0 |
| 97 | Format the microSD card (Pulse Pal 3; Pulse Pal 2 ignores it and does not reply) | none | Lines of ASCII status text; the last contains `!` and ends in `\r\n`. Then 1 / 0, once the default parameters have been reloaded, which can be well after the text. Read this byte before sending the next command |
| 98 | Stop channels | 1 byte, one bit per output channel | none |
| 99 | Set the [screen saver](#screen-saver) | State (0 off, 1 on; Pulse Pal 2 accepts 0 only), timeout in seconds (uint16, 1-65535). Pulse Pal 3 keeps both in its EEPROM; a new device starts with the screen saver on and 1800 s. Used by the MATLAB and Python classes | 1 / 0 |

### Soft triggers and stops

A soft trigger (op 77) starts a channel's pulse train in the next 50 µs cycle. A channel that is
already playing, or waiting out its pulse train delay, ignores it, as it ignores a trigger line
in normal mode. Soft triggers read before that cycle add up: two op 77s in one USB packet trigger
the channels of both. A stop (ops 80, 81 and 98) also cancels a soft trigger that the channel has
not started yet.

### Programming during playback

Parameters programmed during playback (ops 73, 74, 91, 92, a settings file load) take effect at
once, including in trains that are playing. A new resting voltage goes to an idle channel's
output at once. A channel playing a pulse train is not interrupted: it moves to the new resting
voltage at its next transition to rest.

### Screen saver

A Pulse Pal 3 with its screen saver on dims its screen once it has been left alone for the
timeout: no command, no rising edge on a trigger channel, and no joystick click or push. The
next of these brings the screen back, showing the menu as it was left. A joystick click or push
that wakes the screen does nothing else. The screen is written after the reply to the command
that woke it has been sent, and after the timer cycle that handled the trigger, so neither is
delayed.

Op 99 switches the screen saver on or off and sets the timeout; the joystick menu's Screen Saver
item switches it on or off. The device saves both to its EEPROM, but only once no channel is
playing: on a Teensy 4.1, interrupts are off while the EEPROM is written. That takes about
20 µs for each byte that changed, which could move an output edge by up to about 13 µs, and once
in about 2000 changes tens of milliseconds, while a flash sector is erased, which would stop
playback timing and delay a trigger. Change the setting before an experiment rather than during
one.

## Parameter codes (ops 74 and 91)

| Code | Parameter | Value | Range |
|---|---|---|---|
| 1 | Biphasic pulse | 1 byte | 0 or 1 |
| 2 | Phase 1 voltage | uint16 | DAC code |
| 3 | Phase 2 voltage | uint16 | DAC code |
| 4 | Phase 1 duration | uint32 | 1 or more cycles |
| 5 | Inter-phase interval | uint32 | cycles |
| 6 | Phase 2 duration | uint32 | 1 or more cycles |
| 7 | Inter-pulse interval | uint32 | 1 or more cycles; 0 is allowed for biphasic pulses |
| 8 | Burst duration | uint32 | cycles |
| 9 | Burst interval | uint32 | cycles |
| 10 | Pulse train duration | uint32 | cycles |
| 11 | Pulse train delay | uint32 | cycles |
| 12 | Link to trigger channel 1 | 1 byte | 0 or 1 |
| 13 | Link to trigger channel 2 | 1 byte | 0 or 1 |
| 14 | Custom train ID | 1 byte | 0 (none) to the number of custom trains |
| 15 | Custom train target | 1 byte | 0 pulses, 1 bursts |
| 16 | Custom train loop | 1 byte | 0 or 1 |
| 17 | Resting voltage | uint16 | DAC code |
| 18 | Continuous loop mode | 1 byte | 0 or 1 |
| 128 | Trigger mode (trigger channels 1-2) | 1 byte | 0 normal, 1 toggle, 2 pulse gated, 3 param sync (Pulse Pal 3 only) |

The Python and MATLAB classes name these parameters (`phase1_voltage`, `phase1Voltage`, ...), and
give the byte parameters as names (trigger modes "Normal", "Toggle", "Gated", "Param Sync";
custom train targets "Pulses", "Bursts") or as true and false. They send the codes in this table.
Code 18 is `continuous_loop` / `continuousLoop` in the classes.

A phase of 0 cycles would never end, and an inter-pulse interval of 0 would stop a monophasic
train after its first pulse, so ops 73, 74, 91 and 92 and settings files refuse them: the reply
is 0, and the value is set to 1 cycle. A biphasic channel with no inter-pulse interval plays its
pulses back to back. The device checks each channel's parameters together, so to change such a
channel to monophasic, set its inter-pulse interval first.

The clients (MATLAB, Python, C++) and the joystick menu are stricter: see "Value limits" below.

### Value limits

The MATLAB, Python and C++ classes check every value against these limits, and refuse one outside
them before anything is sent. The joystick menu keeps to them too. The device itself accepts any
value that fits its data type, apart from the times of 0 cycles above, so a value outside these
limits can still reach it from older software or an old settings file; the classes read such a
value back as it is (op 93).

| Value | Limit |
|---|---|
| Voltages | -10 to 10 V, sent as the nearest DAC code (a halfway value to the even code) |
| Times | 0 to 9999.9999 s, rounded to the nearest 50 µs cycle (a halfway value to the even cycle). 9999.9999 s (199999998 cycles) is the longest time the joystick menu shows and edits: four digits before the point. The Python and MATLAB classes hold the rounded time, as the device plays it |
| Phase 1 and 2 durations, inter-pulse interval, pulse train duration | At least 2 cycles (100 µs). A trigger channel reads its input once per cycle, so a 1 cycle pulse from another Pulse Pal can fall between two reads; 2 cycles is the shortest pulse a trigger channel detects reliably |
| Custom pulse times, and a custom waveform's sampling period | Multiples of 2 cycles (100 µs), up to 9999.9999 s, each later than the one before. A time between two steps is refused, not rounded, so that a train plays as written |
| Pulses per custom train | 5000 on Pulse Pal 2, 10000 on Pulse Pal 3 (op 94 reports it) |
| Custom train ID | 0 to 2 on Pulse Pal 2, 0 to 4 on Pulse Pal 3 |
| Trigger mode | 0 to 2 on Pulse Pal 2; 3 (param sync) on Pulse Pal 3 only |
| Zero code calibration (op 96) | -0.1 to 0.1 V, on Pulse Pal 3 only: its EEPROM stores it |
| Settings file name (op 90) | 1 to 11 printable ASCII characters followed by `.pps`, 15 in all, so that the joystick menu can list the file |
| Screen saver (op 99) | Timeout 1 to 65535 s. On Pulse Pal 3 only |

In a burst, a pulse starts only if it ends before the burst does: its phase 1, or for a biphasic
pulse the whole pulse, so that the end of the burst never cuts off phase 2. Likewise, a biphasic
pulse starts only if it ends by the end of the pulse train (it may end in the train's last cycle).
A monophasic pulse still starts, and the end of the train cuts it short. Trains in continuous loop
mode, and custom trains that do not loop, do not end at the train duration, so this does not apply
to them.

### Param sync mode (Pulse Pal 3, trigger mode 3)

Param sync mode delays op 92 until a TTL edge, so that the parameters of the next trial can
be sent during the current one and applied the instant it starts.

**Storing a set.** While either trigger channel is in param sync mode, op 92 stores its
parameter set instead of programming it. The confirm byte still reports whether every value
was in range, because values are checked when they arrive. A later op 92 replaces the stored
set, so only the most recent one is ever loaded. An op 92 whose data does not all arrive is
not stored.

**Only op 92 is delayed.** Ops 73, 74 and 91 program the device immediately, in param sync
mode as in any other. In the clients, only `sync_to_device()` (Python, also at the end of a
`batch()` block), `syncToDevice()` (MATLAB) and `syncAllParams()` (C++) store a set; assigning a
parameter with `auto_sync` / `autoSync` on, and the C++ class's methods that set one parameter,
take effect at once.

**At the edge.** A rising edge on a trigger channel in param sync mode loads the stored set.
With nothing stored, it does nothing.

- An idle output channel takes its new parameters in the timer cycle the edge is detected,
  and moves to its new resting voltage.
- An output channel **playing a pulse train** finishes it on the parameters it started with,
  and takes the new ones in the cycle the train ends. So a train that crosses into the next
  trial keeps one shape throughout, and the next trigger plays a whole train with the new
  parameters.
- A channel in continuous loop mode has no train end, so it waits until something stops it.
  A stored set that switches continuous loop mode off does not stop the channel, unlike op 92
  outside param sync mode: nothing on this path interrupts a train in progress.
- The set is copied aside at the edge, so a new op 92 can arrive while channels are still
  finishing their trains. A second edge before they finish replaces what they are waiting for
  with the newer set.
- Nothing else cancels a channel's wait. When the channel takes the set, it replaces
  anything programmed on that channel since the edge: by ops 73, 74 or 91, by op 92 outside
  param sync mode, by loading a settings file, or by the default parameters loaded after a
  comm failure.
- Trigger mode is not an output channel parameter, so it changes at the edge for both
  trigger channels.

**The param sync channel starts and stops nothing.** Its links to output channels are
ignored. This includes the edge that loads a set moving it to another trigger mode: that edge
only loads the set, and the new mode applies from the next edge. To start a train on the same
edge, send the TTL to the other trigger channel as well. Both edges land in the same timer
cycle, and the parameters are loaded first.

**Leaving param sync mode.** Use op 74 or 91. A trigger mode sent with op 92 is stored with
the rest of the set, and takes effect only at a sync edge. When the last trigger channel
leaves the mode, by any route, the stored set is discarded, so putting a channel back into
the mode cannot load a set sent long before. The routes are ops 73, 74 and 91, the joystick
menu, loading a settings file, and the default parameters loaded after a comm failure or an
op 97 format.

The Python, MATLAB and C++ classes take both trigger channels out of param sync mode when
they connect, before programming their default parameters. Otherwise a device left in the
mode by an earlier session would store those defaults instead of running them.

## Settings file

Settings files are 179 bytes, in the `Pulse_Pal` folder on the microSD card:

```
For each output channel 1-4 (42 bytes each):
  phase 1 duration, inter-phase interval, phase 2 duration, inter-pulse interval,
  burst duration, burst interval, pulse train duration, pulse train delay   uint32 each
  biphasic                                                                 uint8
  phase 1 voltage, phase 2 voltage, resting voltage                        uint16 each
  custom train ID, custom train target, custom train loop                  uint8 each
For each trigger channel 1-2 (5 bytes each):
  trigger mode, then 4 bytes linking the trigger to output channels 1-4    uint8 each
End marker: 252                                                            uint8
```

Continuous loop mode is not saved. The device writes `default.pps` with the default
parameters at startup, and the joystick menu cannot overwrite or erase it.

A load (op 90 or the joystick menu) fails, and the device loads the default parameters
instead, if the file:

- is missing, or shorter than 179 bytes;
- lacks the end marker;
- or holds a value the device cannot play: a custom train ID above the device's number of
  custom trains, a biphasic, custom train target or custom train loop byte above 1, or a
  trigger mode the device does not have.

So a file saved on Pulse Pal 3 that uses custom train 3 or 4, or param sync mode, does not
load on Pulse Pal 2.

## Timeouts and error handling

- A read gives up if no further byte arrives for 100 ms. This limits the gap between bytes,
  not the length of a transfer, so a large custom pulse train is never cut short. Clients
  should still send each command in a single write, so that a pause in the client cannot
  split a command.
- On a timeout the device stops all playback, returns the outputs to their resting voltages,
  shows "COMM. FAILURE!", and waits for a joystick click. Until then it reads no commands and
  ignores triggers. After the click it loads the default parameters. A timeout usually means
  a faulty cable, hub or client.
- The interrupted op still sends its reply, if it has one, and that reply can be 1. A confirm
  byte therefore does not reveal a timeout.
- Replies are buffered and sent as one USB packet when the command finishes, so a reply means
  the command is done and the next command can follow at once. For example, a client can read
  the parameters (op 93) as soon as op 90 confirms a settings file load.

## Differences by firmware version

| Firmware | Notes |
|---|---|
| v22 | Current. Adds ops 91-99, and on Pulse Pal 3, custom trains 3 and 4 and param sync trigger mode |
| v21 | No ops 91-98. Clients program parameters with ops 73 and 74, and custom trains with ops 75 and 76 |

Clients read the firmware version from the handshake (op 72), and the device properties from
op 94.

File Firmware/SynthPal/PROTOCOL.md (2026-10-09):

# Synth Pal serial protocol

Synth Pal is alternative firmware for Pulse Pal 3 hardware. Each output channel plays a sine,
triangle, square or sawtooth wave or white noise, or steps to a fixed voltage, when it is
triggered, with its own
amplitude, mean voltage, resting voltage, play duration, and on and off ramps, at one frequency
shared by all four channels. This page is the reference for its USB serial protocol, as of Synth
Pal firmware v1.

| Client | Location |
|---|---|
| Python class | `pulsepal.SynthPalDevice`, in `/Python/PulsePal/pulsepal/synth_pal.py` |
| MATLAB class | `/MATLAB/@SynthPalDevice/SynthPalDevice.m` |

On the device, `processUSBCommands()` in `/Firmware/SynthPal/USBOps.ino` executes commands, and
the `OpCode` enum in `/Firmware/SynthPal/SynthPal.ino` defines the codes.

**The numbers on this page are fixed** once a client has been released: installed clients use
these op codes and message layouts. New functionality gets a new op code.

## Message format

Every command from the PC is:

```
213, op code, op-specific data
```

This is the Pulse Pal framing: bytes that do not start with 213 are ignored. Ops 72, 81, 89 and
99 are Pulse Pal's ops of the same numbers; the others are ASCII letters, as in Wave Pal.

- Multi-byte values are little-endian.
- Frequencies are in hundredths of a Hz (centiHz), voltages in microvolts, and durations in
  microseconds.
- Ops that set an output channel setting take one value per output channel, for channels 1-4.
  Ops that take several channels at once use one bit per channel (bit 0 = channel 1); bits 4-7
  are ignored.

## Connecting

The Python and MATLAB classes connect in this order:

1. Op 72 (handshake). A Synth Pal replies `83` ('S'). A Pulse Pal replies `75` ('K') and a Wave
   Pal `87` ('W') to the same op, so each client can tell which firmware a device runs, and say
   so. The Pulse Pal and Wave Pal clients do the same for a Synth Pal. A firmware version newer
   than the client knows is used, with a warning: new firmware only adds ops. As for Pulse Pal
   (see its [connection steps](../PROTOCOL.md#connecting)), the clients discard the bytes waiting
   before op 72, then read its reply until the device has been quiet for 50 ms and take the last
   5 bytes, which skips a reply to a command an earlier session left queued on the device.
2. Op 78 ('N'): hardware properties and limits.
3. Op 89: the client's name, "PYTHON" or "MATLAB", shown as "PYTHON Connected".
4. Op 88 ('X') with all four channel bits, then the default settings: ops 70, 77, 65, 87, 86,
   68, 66, 69, 84 and 73. In this order each is valid whatever the device holds (see
   [Levels](#levels)): a mean voltage of 0 V (op 77) goes with any amplitude, the default
   amplitude of 5 V (op 65) then goes with any waveform, a sine wave (op 87) then goes with both,
   and a resting voltage (op 86) goes with any waveform. These ops apply at once also on a device left in
   [param sync mode](#param-sync-trigger-mode-3), and op 84 takes both trigger channels out of
   it, which discards a stored set.

When they close, they send op 81, which stops playback and puts "Synth Pal v3.0" back on the
screen.

## Confirm bytes

Ops marked "1 / 0" reply with one byte: 1 if the command was executed, 0 if it was rejected
because a value was out of range. A rejected command changes nothing. Its data is still read,
so that it is not taken for the next command.

## Op codes

| Op | Char | Name | Data after the op code | Reply |
|---|---|---|---|---|
| 72 | `H` | Handshake | none | `83` ('S'), then firmware version (uint32) |
| 78 | `N` | Hardware info | none | Hardware version (uint8), number of output channels (uint8), lowest frequency in centiHz (uint32), highest frequency in centiHz (uint32), highest sampling rate in Hz (uint32), sample clock's timer clock in Hz (uint32), longest play duration in µs (uint32) |
| 70 | `F` | Set frequency | Frequency in centiHz (uint32), 100 to 2000000 (1 Hz to 20 kHz) | 1 / 0, then samples per cycle (uint32). Always 5 bytes: after a 0, the samples per cycle of the frequency in use |
| 87 | `W` | Set waveforms | 4 bytes, one per output channel, see [Waveforms](#waveforms) | 1 / 0 |
| 65 | `A` | Set amplitudes | 4 int32, one per output channel, in µV: peak to peak, 0 to 20000000, or for a fixed voltage the voltage, -10000000 to 10000000. See [Levels](#levels) | 1 / 0 |
| 86 | `V` | Set resting voltages | 4 int32, one per output channel: in µV, -10000000 to 10000000. See [Levels](#levels) | 1 / 0 |
| 77 | `M` | Set mean voltages | 4 int32, one per output channel: in µV, -10000000 to 10000000. See [Levels](#levels) | 1 / 0 |
| 68 | `D` | Set play durations | 4 uint32, one per output channel: in µs, 0 to 3600000000. 0 plays until stopped. See [Ramps](#ramps) | 1 / 0 |
| 66 | `B` | Set on ramp durations (at the Beginning) | 4 uint32, one per output channel: in µs, 0 to 3600000000. 0 for no ramp. See [Ramps](#ramps) | 1 / 0 |
| 69 | `E` | Set off ramp durations (at the End) | 4 uint32, one per output channel: in µs, 0 to 3600000000. 0 for no ramp. See [Ramps](#ramps) | 1 / 0 |
| 84 | `T` | Set trigger modes | 2 bytes, one per trigger channel, see [Triggers](#triggers) | 1 / 0 |
| 85 | `U` | Set all settings: applied at once, or stored for a param sync edge (see [Param sync](#param-sync-trigger-mode-3)) | 114 bytes: frequency in centiHz (uint32), then for channels 1-4: waveforms (4 bytes), amplitudes, mean voltages and resting voltages (4 int32 each), play durations, on ramp durations and off ramp durations (4 uint32 each); then trigger links (8 bytes, as op 73) and trigger modes (2 bytes, as op 84). Each value as in the op that sets it alone | 1 / 0 |
| 82 | `R` | Get all settings: those the device plays now | none | 114 bytes, in op 85's layout. See [Reading the settings back](#reading-the-settings-back) |
| 73 | `I` | Set trigger links | 8 bytes: trigger channel 1's links to output channels 1-4, then trigger channel 2's. Each is 1 (linked) or 0 | 1 / 0 |
| 80 | `P` | Soft trigger: starts idle channels | Channel bits (uint8) | none |
| 88 | `X` | Stop | Channel bits (uint8) | none |
| 71 | `G` | Get status | none | Playing channel bits (uint8: a channel in its off ramp counts as playing, until it reaches its resting voltage), samples per cycle (uint32), the output range of channels 1-4 (4 uint8, see [Output ranges](#output-ranges)), longest sample clock interrupt since the previous op 71, in nanoseconds (uint32), late output updates since the previous op 71 (uint32, see [Timing](#timing)) |
| 89 | `Y` | Set the client name | 6 characters, shown on the top screen as "NAME Connected" | none |
| 81 | `Q` | Disconnect: stop all channels, and show the device's own name on the top screen again | none | none |
| 99 | `c` | Set the screen saver | State (uint8: 0 off, 1 on), timeout in seconds (uint16, 1-65535) | 1 / 0 |
| 90 | `Z` | Playback checksums (testing) | none | For channels 1-4: samples played since the channel last started (4 uint32), then the sum of their DAC codes, modulo 2^32 (4 uint32) |

Ops 72, 81, 89 and 99 are Pulse Pal's ops of the same numbers. Like Pulse Pal's op 81, Synth
Pal's stops every channel, as op 88 does (over their off ramps), so that closing a client stops
its outputs on all three firmwares. The settings stay: TTL triggers still play the channels after
the client closes. Op 99 works as in Pulse Pal firmware (see its
[screen saver](../PROTOCOL.md#screen-saver) notes), with the settings at the same EEPROM
addresses, so they carry over when a device changes firmware.

### Reading the settings back

Op 82 returns every setting in op 85's layout: the settings the device plays now, including
changes made with the joystick menu. The Python and MATLAB classes read it in
`sync_from_device()` / `syncFromDevice()`. A set that op 85 stored for a param sync edge is not
part of it until the edge loads it. After the edge, an output channel still finishing on its old
settings (see [Param sync](#param-sync-trigger-mode-3)) is reported with them until it takes the
new ones; the frequency and the trigger modes are the new ones at once.

The device holds one amplitude per channel (see [Levels](#levels)). The classes keep a channel's
peak to peak voltage and its fixed voltage apart, so they put a Fixed Voltage channel's amplitude
in its fixed voltage, and any other channel's in its peak to peak voltage. They keep their own
value of the other one, reduced if need be to suit the mean voltage read back.

Op 90 is for testing, like Wave Pal's op 90: `/Python/PulsePal/tests/synthpal_hardware_test.py`
and `/MATLAB/tests/testSynthPalDevice.m` use it to check the samples a device played. While a
channel plays, its count includes its next sample, which is computed one sample period before it
reaches the output. Once the channel has stopped, the count and the sum are of the samples that
reached the output, however it stopped: at the end of its play duration, or by op 88, a toggle or
gated trigger edge, or the menu. A frequency change during playback rescales the count to the new
sampling rate (it keeps the time left to play), so after one the count is no longer exact.

Every setting takes effect at once, also during playback. A new frequency keeps each playing
channel's place in its cycle, the time it has left to play and the level its ramp has reached. A
new play duration counts from the end of the channel's on ramp: a channel that has already played
longer stops on its next sample (and starts its off ramp). A new ramp duration applies to a ramp
under way from the level it has reached.

## Frequency and sampling

One frequency applies to all four output channels. Each cycle of a waveform is a fixed number of
samples, `samplesPerCycle`: the largest multiple of 4 whose sampling rate (`samplesPerCycle`
times the frequency) is at most 100 kHz. Because it is a whole number, every cycle is rendered
the same way, and because it is a multiple of 4, a sample falls on every vertical edge (square,
sawtooth), peak and trough (sine, triangle). Op 70 replies with it.

| Frequency | Samples per cycle | Sampling rate |
|---|---|---|
| 1 Hz | 100000 | 100 kHz |
| 100 Hz | 1000 | 100 kHz |
| 300 Hz | 332 | 99.6 kHz |
| 500 Hz | 200 | 100 kHz |
| 12.6 kHz | 4 | 50.4 kHz |
| 20 kHz | 4 | 80 kHz |

The sample clock counts a 24 MHz clock (op 78 reports it), so a sample period is a whole number
of its ticks (41.7 ns). Where the exact period is not, periods alternate between two lengths a
tick apart, so that every sample comes within one tick of its exact time. The frequency played
is exact, to the accuracy of the device's crystal.

Play durations are counted in samples: a duration is rounded to the nearest sample at the
sampling rate in use, and a nonzero duration lasts at least one sample.

## Waveforms

| Code | Name | One cycle, from the trigger |
|---|---|---|
| 0 | Sine | Starts at the mean voltage, rising. Peak at a quarter cycle, trough at three quarters |
| 1 | Triangle | Starts at the mean voltage, rising. Peak at a quarter cycle, trough at three quarters |
| 2 | Square | High for the first half cycle, low for the second |
| 3 | Sawtooth | Rises in equal steps from its lowest voltage, at the first sample, to its highest, at the last, then falls back |
| 4 | Fixed Voltage | Not periodic: steps to the amplitude, a voltage, and holds it for the play duration |
| 5 | White Noise | Not periodic: a new random voltage on every sample, uniform over the amplitude (peak to peak) around the mean voltage |

The codes are fixed: a new waveform takes the next code.

A channel without an off ramp that stops, at the end of its play duration or otherwise, returns
to its resting voltage on the next sample, part way through a cycle if need be.

A fixed voltage plays like the other waveforms: it starts on the sample clock, as they do (about
8 µs after a trigger when no channel plays), lasts its play duration in samples, and stops and
responds to the trigger modes in the same way. Its output is written to the DAC once, as it
starts, and once more as it stops. The frequency does not change it, except through the sampling
rate that its play duration is counted in.

White noise is rendered at the sampling rate the frequency sets (see
[Frequency and sampling](#frequency-and-sampling)): each sample is a new random value, uniform
from the mean voltage minus half the amplitude to the mean voltage plus half of it, so the frequency
sets only how often it changes, and no claim is made about its spectrum. Otherwise it plays as the
periodic waveforms do: its amplitude is peak to peak, it follows the same [levels](#levels) rule
and output ranges, and the ramps scale it and move its mean in the same way. Each channel has its
own random sequence (xoshiro128+), which carries on from one playback to the next, so every
playback is new noise and the channels are unrelated. The sequences start from the same point
when the device powers up. The playback checksums of op 90 cannot be predicted for noise: the
hardware tests check their statistics instead.

## Levels

A channel's waveform (or white noise) swings half its amplitude above and below its mean
voltage, which is the waveform's mean. The whole waveform must stay within -10 V to 10 V:

```
2 * |mean voltage| + amplitude <= 20 V
```

The channel outputs its resting voltage while it is idle, anywhere within -10 V to 10 V, with
any waveform. The ramps lead from it to the waveform and back (see [Ramps](#ramps)); without
them, the output steps from the resting voltage to the waveform at a trigger, and back when it
stops.

A fixed voltage (waveform 4) reads the amplitude differently: the amplitude is the voltage the
output steps to, -10 V to 10 V, and may be negative. The mean voltage does not apply to it. Only
a fixed voltage takes a negative amplitude.

Op 65 checks the new amplitudes against the waveforms and mean voltages the device holds, op 77
the new mean voltages against its waveforms and amplitudes, and op 87 the new waveforms against
its amplitudes and mean voltages. Each replies 0 if any channel would break these rules. So to
raise an amplitude beyond what a channel's mean voltage allows, send the mean voltage first; and
to change a waveform, send an amplitude that suits both the old waveform and the new one first
(an amplitude of 0 goes with every waveform and mean voltage), or change the amplitude after the
waveform. For example, from a fixed voltage of -5 V to a sine wave of 4 V peak to peak: op 65
with 4 V, then op 87.

The Python and MATLAB classes keep a periodic waveform's peak to peak voltage and a fixed voltage
as two settings (`peak_to_peak` and `fixed_voltage`, `peakToPeak` and `fixedVoltage`), and send
whichever the channel's waveform uses as its amplitude. They work out an order of ops 65, 87 and
77 that the device accepts at each step: each channel first takes an amplitude that suits its
current and its new waveform and mean voltage (its current amplitude, else its new one, else 0 V,
which suits any), then the waveforms, the mean voltages and the new amplitudes follow. If the
device refuses a step, the classes start again from an amplitude of 0 V on every channel.

At full amplitude, each sample is the mean voltage's DAC code plus an offset rounded half away
from zero, so samples the same distance above and below the mean voltage are the same number of
codes from it: when the mean voltage falls exactly on a DAC code (as 0 V does in the bipolar
ranges), the mean of any whole number of cycles is exactly that code. A fixed voltage is rounded to its
nearest DAC code, as the resting voltage is. The top of a range is one DAC step above the DAC's
highest code, so a waveform that reaches it stops one step short.

### Output ranges

The DAC is an AD5754R with its internal 2.5 V reference, and each output channel has its own
output range. The device chooses it from the channel's levels: the first range in this order
that holds the whole waveform and the resting voltage, which gives the finest steps (the ramps
stay between the two). For a fixed voltage, the range holds the fixed voltage and the resting
voltage.

| Index | Range | Step |
|---|---|---|
| 0 | 0 V to 5 V | 76 µV |
| 1 | 0 V to 10 V | 153 µV |
| 2 | -5 V to 5 V | 153 µV |
| 3 | -10 V to 10 V | 305 µV |

Op 71 reports each channel's range. A change of range on a playing channel writes the range and
the channel's current sample together, so the output shows its old code in the new range only
for a fraction of a microsecond. The zero code calibration that Pulse Pal firmware stores in
EEPROM (Pulse Pal op 96) is applied in the -10 V to 10 V range, the range it was measured in.

## Ramps

Each channel can fade in after a trigger, and fade out when it stops. At an envelope e, from 0 to
1, the output is the resting voltage plus e times (the waveform at full amplitude minus the
resting voltage): the amplitude scales with e, and the waveform's mean moves in a straight line
from the resting voltage to the mean voltage. A fixed voltage ramps in a straight line from the
resting voltage to its voltage.

- **On ramp** (op 66), N samples: the envelope rises linearly, 0, 1/N, ... (N-1)/N. The first
  sample after the trigger is the resting voltage.
- **Play duration** (op 68), at full amplitude. It counts from the end of the on ramp.
- **Off ramp** (op 69), M samples: the envelope falls linearly, 1, (M-1)/M, ... 1/M, and the
  next sample is the resting voltage. It starts at the end of the play duration, or when the
  channel is stopped: op 88, a toggle or gated trigger edge, the menu, or a comm failure.

So the ramps lengthen playback: from a trigger to the resting voltage takes the on ramp, the play
duration and the off ramp, each rounded to whole samples as play durations are (see
[Frequency and sampling](#frequency-and-sampling)). With a play duration of 0, the channel plays
at full amplitude until it is stopped. A ramp of 0 (the default) means no ramp: the output steps.

The envelope never jumps:

- A channel stopped during its on ramp falls from the level it has reached, at the off ramp's
  rate (taking that fraction of the off ramp).
- A channel in its off ramp counts as stopping. A trigger (or op 80) starts it again: it rises
  from the level it has reached, at the on ramp's rate, without starting its waveform's cycle
  again, then plays its play duration again and its off ramp. With no on ramp, it returns to
  full amplitude at once.
- A change of a ramp's duration (op 66 or 69) applies to that ramp from the level it has reached.

## Triggers

Each trigger channel has a trigger mode (op 84). These are Pulse Pal's trigger modes, with the
same codes. An edge on a trigger channel acts on the output channels linked to it (op 73):

| Mode | Name | Rising edge | Falling edge |
|---|---|---|---|
| 0 | Normal | Starts idle channels. Channels that are playing ignore it | Nothing |
| 1 | Toggle | Starts idle channels, and stops channels that are playing | Nothing |
| 2 | Gated | Starts idle channels. Channels that are playing ignore it | Stops the channels, unless the other trigger channel is also gated, linked to them, and still high |
| 3 | Param Sync | Loads the settings op 85 stored, if any. Starts and stops nothing: its links are ignored | Nothing |

A channel in its off ramp counts as idle here: a rising edge starts it again (see
[Ramps](#ramps)). With a play duration of 0, a channel in gated mode plays for exactly as long as
the TTL is high, plus its off ramp.
A soft trigger (op 80) starts idle channels, and channels that are playing ignore it, as in Pulse
Pal firmware. Op 88 stops channels.

### Param sync (trigger mode 3)

Param sync mode, as in Pulse Pal 3 firmware (see its
[param sync](../PROTOCOL.md#param-sync-mode-pulse-pal-3-trigger-mode-3) notes), lets the settings
of the next trial be sent during the current one, and applied the instant it starts.

**Storing a set.** Op 85 carries every setting at once. While either trigger channel is in param
sync mode, the device stores the set instead of applying it. The confirm byte reports whether
every value was in range, and every channel's levels suit its waveform (see [Levels](#levels)):
the set is checked whole, so its settings may be in any order. A rejected set is not stored, and
a later op 85 replaces a stored set. Outside param sync mode, op 85 applies the set at once.

**Only op 85 is delayed.** The ops that set one setting (70, 87, 65, 77, 86, 68, 66, 69, 84, 73)
apply at once, in param sync mode as in any other. The Python and MATLAB classes send op 85 from
`sync_to_device()` / `syncToDevice()`, with their `auto_sync` / `autoSync` switch off, and the
Python class at the end of a `batch()` block.

**At the edge.** A rising edge on a trigger channel in param sync mode loads the stored set. With
nothing stored, it does nothing.

- The frequency and both trigger modes change at once: they are shared by all output channels.
- An output channel at its resting voltage takes its new settings at once: waveform, levels,
  play duration, ramps and trigger links.
- An output channel that is playing, off ramp included, finishes on the settings it started
  with, but at the new frequency, and takes its new settings the moment it reaches its resting
  voltage. So the next trigger plays the new settings. A second edge before then gives it the
  newer set.
- The set is copied aside at the edge, so op 85 can store the next set meanwhile.
- A trigger mode in the set applies from the next edge: the edge that loads it only loads it.

**The param sync channel starts and stops nothing.** Its links to output channels are ignored. To
start channels on the same edge, wire the TTL to the other trigger channel as well: the settings
load first, whichever trigger channel's interrupt runs first, so the channels it starts play the
new settings.

**Leaving param sync mode.** Use op 84 (op 85 in param sync mode is stored with the rest of the
set). When no trigger channel is left in the mode, by op 84, the menu, or the default settings
after a comm failure, the stored set is discarded, so putting a channel back into the mode cannot
load a set sent long before.

**Time at the edge.** Loading a set takes about 2 µs of interrupt time with all four channels at
rest, plus about 2.5 µs for each channel whose output range changes (12 µs measured with all four
changing range and a new frequency); a channel started by the same TTL starts that much later
than usual. While channels play, range changes are left to the sample clock, one channel per
tick, and an edge that changes the frequency takes about 3 µs, which can make one output update
late, as op 70 can (see [Timing](#timing)).

### Timing

All channels share one sample clock, which runs only while a channel is playing.

- **Starting from idle.** When no channel is playing, a trigger computes the first samples and
  starts the sample clock from that moment. The first samples reach the outputs a fixed time
  after the trigger, about 8 µs, and the following ones at exact sample intervals.
- **Starting while another channel plays.** The channel starts on the next tick of the running
  sample clock, so its onset can be up to one sample period late (10 µs at 100 kHz).
- **Output updates.** All outputs change together, 7.5 µs after each tick of the sample clock,
  however many channels change. An update whose DAC writes ran late (for example because the
  firmware's interrupts were held off by a frequency change during playback) is counted in op
  71's late updates, which are normally 0.
- **Trigger pulses** must be longer than a few microseconds. Edges are caught by interrupts, not
  by polling, so the pulse only has to outlast the interrupt latency.

## Timeouts and error handling

As in Pulse Pal firmware (see `/Firmware/PROTOCOL.md`): a read gives up if no byte arrives for
100 ms. The device then stops all playback, shows "COMM. FAILURE!", and waits for a joystick
click; it then loads the default settings. Replies are buffered and sent when the command
finishes.

## Default settings

At startup and after a comm failure: 100 Hz, and on every output channel a sine wave of 5 V peak
to peak around a mean voltage of 0 V, resting at 0 V, played for 1 second, with no ramps. Both trigger channels in normal
mode, and output channels 1-4 linked to trigger channel 1 and not to trigger channel 2. The
Python and MATLAB classes program the same defaults when they connect.

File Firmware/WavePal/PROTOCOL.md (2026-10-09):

# Wave Pal serial protocol

Wave Pal is alternative firmware for Pulse Pal 3 hardware. It stores one sampled waveform per
output channel on the microSD card, and plays it when the channel is triggered. This page is
the reference for its USB serial protocol, as of Wave Pal firmware v1.

| Client | Location |
|---|---|
| Python class | `pulsepal.WavePalDevice`, in `/Python/PulsePal/pulsepal/wave_pal.py` |
| MATLAB class | `/MATLAB/@WavePalDevice/WavePalDevice.m` |

On the device, `processUSBCommands()` in `/Firmware/WavePal/USBOps.ino` executes commands, and
the `OpCode` enum in `/Firmware/WavePal/WavePal.ino` defines the codes.

**The numbers on this page are fixed** once a client has been released: installed clients use
these op codes and message layouts. New functionality gets a new op code.

## Message format

Every command from the PC is:

```
213, op code, op-specific data
```

This is the Pulse Pal framing: bytes that do not start with 213 are ignored. Op codes are the
ASCII letters of the matching WavePlayer ops (Bpod Analog Output Module), where one exists.

- Multi-byte values are little-endian.
- Samples and voltages are 16-bit DAC codes, mapped onto the current output range: code 0 is
  the bottom of the range and 65535 the top. 0 V is code 32768 in the bipolar ranges and 0 in
  the unipolar ones.
- Ops that take one output channel number it 1-4. Ops that take several use one bit per
  channel (bit 0 = channel 1); bits 4-7 must be 0.
- Times are in samples of the current sampling rate.

## Connecting

The Python and MATLAB classes connect in this order:

1. Op 72 (handshake). A Wave Pal replies `87` ('W'). A Pulse Pal replies `75` ('K') to the
   same op, and a Synth Pal (`/Firmware/SynthPal`) `83` ('S'), so each client can tell which
   firmware a device runs, and say so. The Pulse Pal and Synth Pal clients do the same the
   other way round. A firmware version newer than the client knows is used, with a warning:
   new firmware only adds ops. As for Pulse Pal (see its
   [connection steps](../PROTOCOL.md#connecting)), the clients discard the bytes waiting before
   op 72, then read its reply until the device has been quiet for 50 ms and take the last 5
   bytes, which skips a reply to a command an earlier session left queued on the device.
2. Op 78 ('N'): hardware properties.
3. Op 89: the client's name, "PYTHON" or "MATLAB", shown as "PYTHON Connected".
4. Op 88 ('X') with all four channel bits, then the default settings: ops 83, 82, 79, 68,
   84 and 73.

When they close, they send op 81, which stops playback and puts "Wave Pal v3.0" back on the
screen.

Waveforms loaded by an earlier session stay on the device unless op 82 changes the output
range.

## Confirm bytes

Ops marked "1 / 0" reply with one byte: 1 if the command was executed, 0 if it was rejected
because a value was out of range. A rejected command changes nothing. Op 76 also replies 0 if
the waveform could not be written to the microSD card; that channel is then left empty.

## Op codes

| Op | Char | Name | Data after the op code | Reply |
|---|---|---|---|---|
| 72 | `H` | Handshake | none | `87` ('W'), then firmware version (uint32) |
| 78 | `N` | Hardware info | none | Hardware version (uint8), number of output channels (uint8), maximum samples per waveform (uint32), maximum sampling rate in Hz (uint32), samples per playback buffer (uint32), sample clock in Hz (uint32) |
| 83 | `S` | Set sampling rate | Rate in Hz (uint32), 1 to the maximum | 1 / 0 |
| 82 | `R` | Set output range | Range index (uint8), see [Output ranges](#output-ranges) | 1 / 0 |
| 76 | `L` | Load waveform | Channel (uint8, 1-4), sample count (uint32, 1 to the maximum), then that many samples (uint16 each) | 1 / 0, once the waveform is on the microSD card |
| 80 | `P` | Soft trigger: starts idle channels | Channel bits (uint8) | none |
| 88 | `X` | Stop | Channel bits (uint8) | none |
| 33 | `!` | Set fixed voltage | Channel bits (uint8), DAC code (uint16) | 1 / 0 |
| 79 | `O` | Set loop mode | 4 bytes, one per output channel: 0 off, 1 on | 1 / 0 |
| 68 | `D` | Set loop duration | 4 uint32, one per output channel: samples, 0 = loop until stopped | 1 / 0 |
| 84 | `T` | Set trigger modes | 2 bytes, one per trigger channel, see [Triggers](#triggers) | 1 / 0 |
| 73 | `I` | Set trigger links | 8 bytes: trigger channel 1's links to output channels 1-4, then trigger channel 2's. Each is 1 (linked) or 0 | 1 / 0 |
| 71 | `G` | Get status | none | Playing channel bits (uint8), samples loaded on channels 1-4 (4 uint32, 0 = empty), underruns on channels 1-4 (4 uint32, counted since startup), longest playback interrupt since the previous op 71, in nanoseconds (uint32) |
| 89 | `Y` | Set the client name | 6 characters, shown on the top screen as "NAME Connected" | none |
| 81 | `Q` | Disconnect: stop all channels, and show the device's own name on the top screen again | none | none |
| 99 | `c` | Set the screen saver | State (uint8: 0 off, 1 on), timeout in seconds (uint16, 1-65535) | 1 / 0 |
| 90 | `Z` | Playback checksums (testing) | none | For channels 1-4: samples played since the channel last started (4 uint32), then the sum of their DAC codes, modulo 2^32 (4 uint32) |

Ops 72, 81, 89 and 99 are Pulse Pal's ops of the same numbers, so that a client shows its name on
the screen in the same way. Like Pulse Pal's op 81, Wave Pal's stops every channel, as op 88 does,
so that closing a client stops its outputs on all three firmwares. The settings and waveforms
stay: TTL triggers still play them after the client closes. Op 99 works as in Pulse Pal firmware
(see its [screen saver](../PROTOCOL.md#screen-saver) notes), with the settings at the same EEPROM
addresses, so they carry over when a device changes firmware. The device saves them only while no
channel is playing, so a change made during playback is saved when it stops.

Op 90 is for testing, like Pulse Pal's debugging ops 86 and 87: `/Python/PulsePal/tests/wavepal_hardware_test.py`
and `/MATLAB/tests/testWavePalDevice.m` use it to check every sample a device played against the waveform
they loaded.

Op 76 stops its channel before it reads the samples. Other channels keep playing, and are fed
from the microSD card between the blocks of the transfer.

Op 33 stops playback on its channels. The voltage holds until the channel plays or is stopped.

Op 83 takes effect at once, also during playback. Loop durations are counted in samples, so a
client that keeps them in seconds sends op 68 again after op 83, as the Python and MATLAB
classes do.

### Output ranges

The DAC is an AD5754R with its internal 2.5 V reference. The ranges are WavePlayer's, without its
12 V ranges, which need the Analog Output Module's external reference. So the indices differ
from WavePlayer's.

| Index | Range | 0 V code |
|---|---|---|
| 0 | 0 V to 5 V | 0 |
| 1 | 0 V to 10 V | 0 |
| 2 | -5 V to 5 V | 32768 |
| 3 | -10 V to 10 V (default) | 32768 |

Samples are DAC codes, so they mean a different voltage in another range. When op 82 changes
the range, the device stops all playback, sets every output to 0 V and **unloads every
waveform**, so that nothing plays at a voltage it was not made for. The client sends them
again, encoded for the new range. Op 82 with the range already in use changes nothing.

The zero code calibration that Pulse Pal firmware stores in EEPROM (Pulse Pal op 96) is applied
in the -10 V to 10 V range, the range it was measured in.

## Triggers

Each trigger channel has a trigger mode (op 84), as in Pulse Pal firmware, and modes 0-2 are Pulse
Pal's trigger modes, with the same codes. An edge on a trigger channel acts on the output channels
linked to it (op 73):

| Mode | Name | Rising edge | Falling edge |
|---|---|---|---|
| 0 | Normal | Starts idle channels. Channels that are playing ignore it | Nothing |
| 1 | Toggle | Starts idle channels, and stops channels that are playing | Nothing |
| 2 | Gated | Starts idle channels. Channels that are playing ignore it | Stops the channels, unless the other trigger channel is also gated, linked to them, and still high |
| 4 | Master | Starts idle channels, and restarts channels that are playing from their first sample | Nothing |

Mode 3 is Pulse Pal's param sync mode, which Wave Pal does not have: op 84 replies 0 to it. With
loop mode on and a loop duration of 0, a channel in gated mode plays for exactly as long as the TTL
is high.

A soft trigger (op 80) starts idle channels, and channels that are playing ignore it, as in Pulse
Pal firmware, whatever the trigger modes. A channel with no waveform ignores triggers. Op 88 stops
channels.

A channel stops when:

- its last sample has played and loop mode is off;
- in loop mode, when the loop duration has elapsed (a duration of 0 loops until stopped);
- op 88, op 33, op 82 (range change), op 76 on that channel, a toggle or gated trigger, or the
  joystick menu stops it.

A stopped channel outputs 0 V. After the last sample, the output returns to 0 V one sample
period later.

### Timing

All channels share one sample clock, which runs only while a channel is playing.

- **Starting from idle.** When no channel is playing, a trigger writes the first sample at
  once, a few microseconds after the edge, and starts the sample clock from that moment. The
  following samples come at exact sample intervals.
- **Starting while another channel plays.** The channel starts on the next tick of the running
  sample clock, so its onset can be up to one sample period late (10 µs at 100 kHz).
- **Rate.** The sample clock divides a 24 MHz clock (op 78 reports it) by a whole number, so the
  rate played is 24 MHz / round(24 MHz / rate). For example, 44100 Hz plays at 44117.6 Hz.
- **Trigger pulses** must be longer than a few microseconds. Edges are caught by interrupts,
  not by polling, so the pulse only has to outlast the interrupt latency.

## Storage and buffering

- Each waveform's first 16384 samples (op 78 reports the number) are kept in RAM from the
  moment it is loaded, so playback starts without waiting for the microSD card. A waveform no
  longer than that plays entirely from RAM.
- The rest is read from the card in blocks of the same size, while the previous block plays.
  Each channel has two buffers for this (`channel1BufferA` and `channel1BufferB` for channel 1,
  and so on).
- If a block is not read in time (an **underrun**), the output holds its last value until the
  block arrives, then continues where the waveform should be by then, so the waveform keeps its
  timing. Op 71 counts underruns per channel. Underruns are most likely while op 76 writes to a
  slow card during playback on other channels.
- The waveforms are kept in `/Wave_Pal/WaveData.wfm`, which the device creates at startup, with
  a 2 MiB region per channel. Loaded waveforms do not survive a restart.
- Wave Pal needs a FAT16 or FAT32 card (Pulse Pal's own format). It stops at startup with an
  error message on an exFAT card.
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

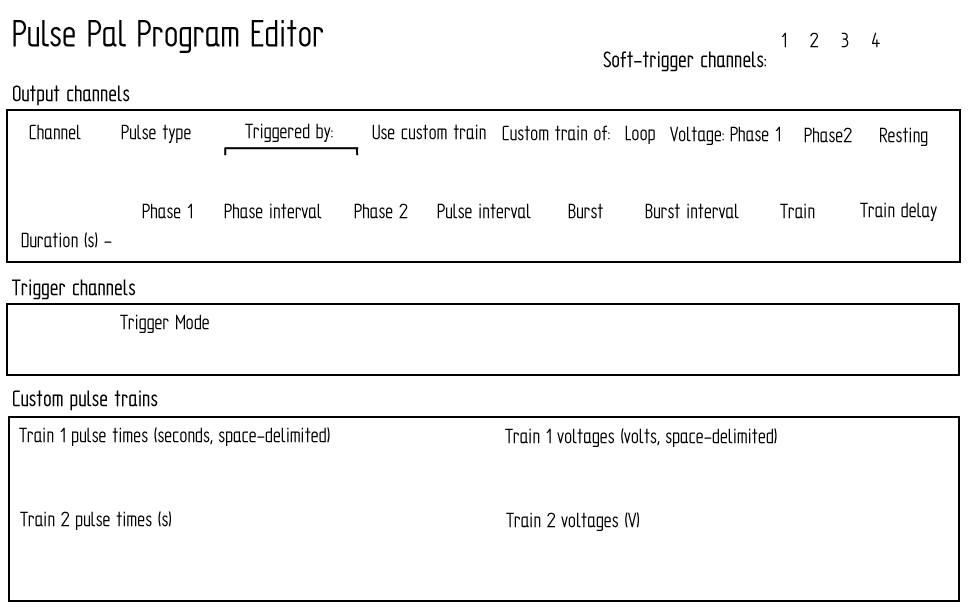
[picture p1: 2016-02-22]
MATLAB/Media/ProgrammerBG.bmp

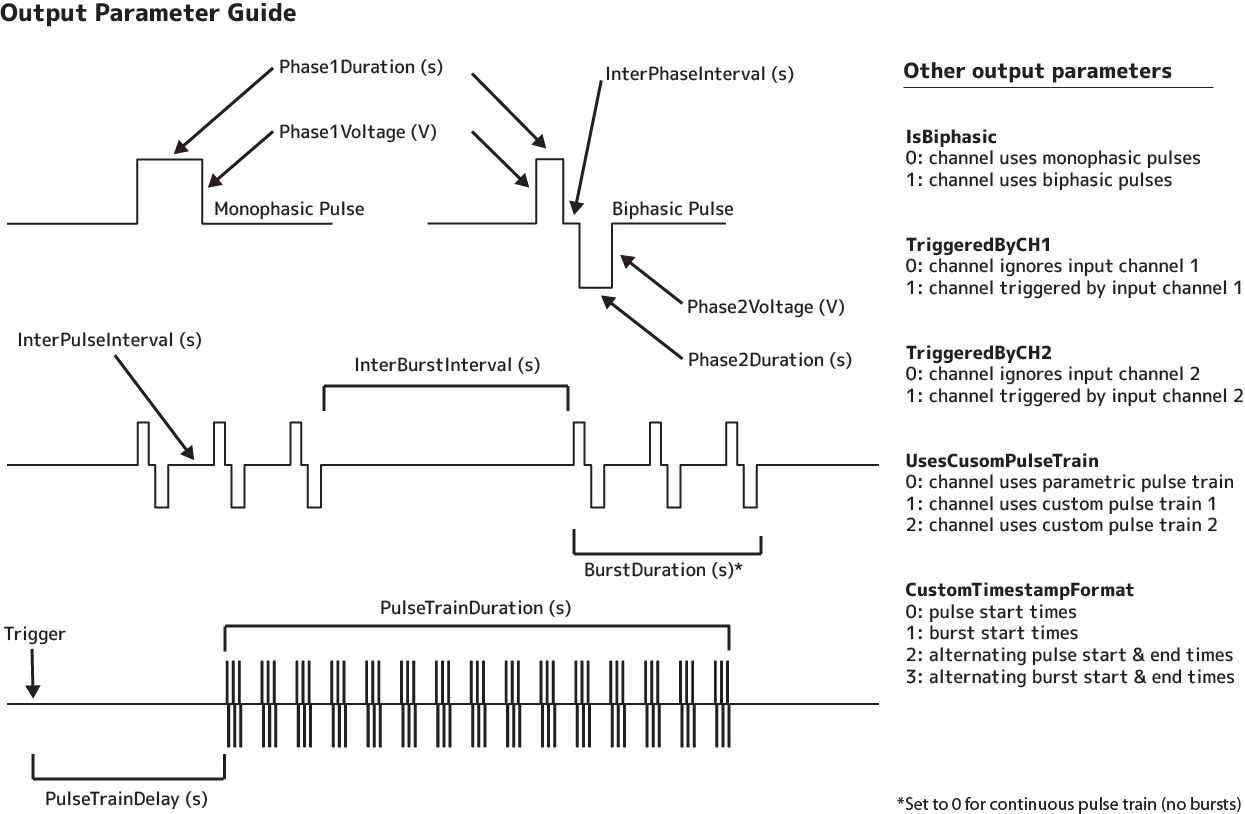
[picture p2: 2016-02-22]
MATLAB/Media/OutputParameterExamples.bmp

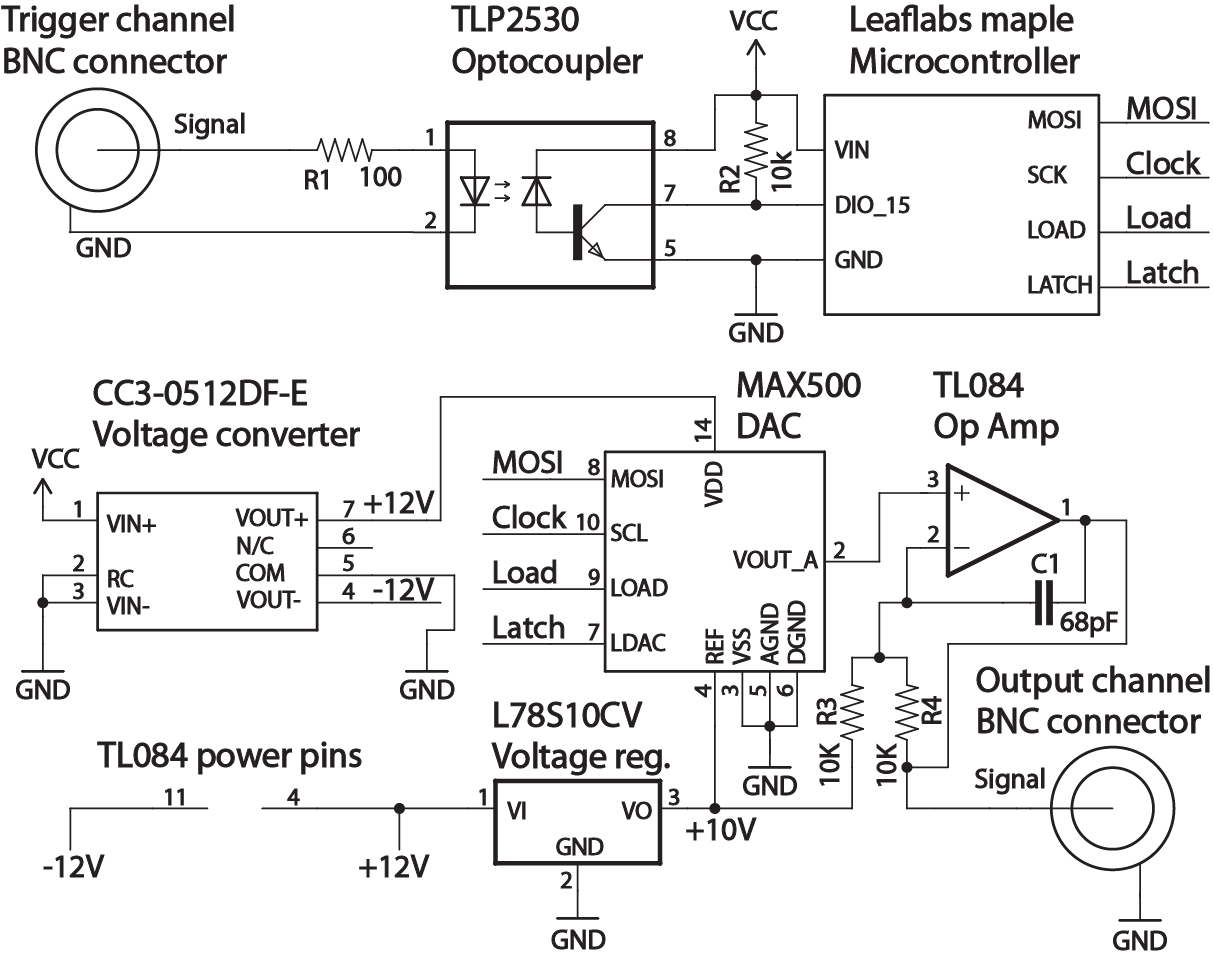
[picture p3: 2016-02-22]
CAD/PCB/r1_1/Essential io circuit.png

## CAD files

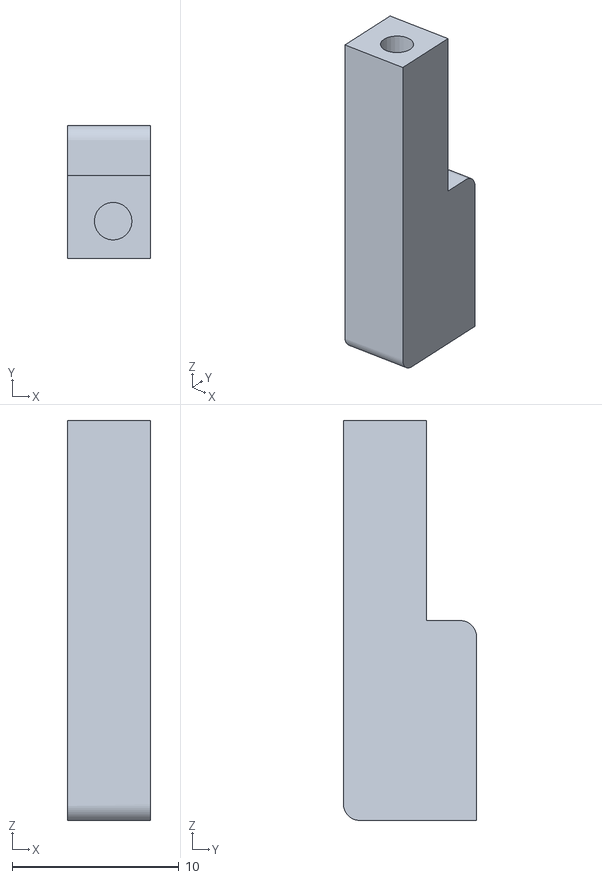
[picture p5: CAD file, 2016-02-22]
CAD/Enclosure/Pulse Pal 1_X/v1.1_ScreenSupport.stl
5.00 x 8.00 x 24.0

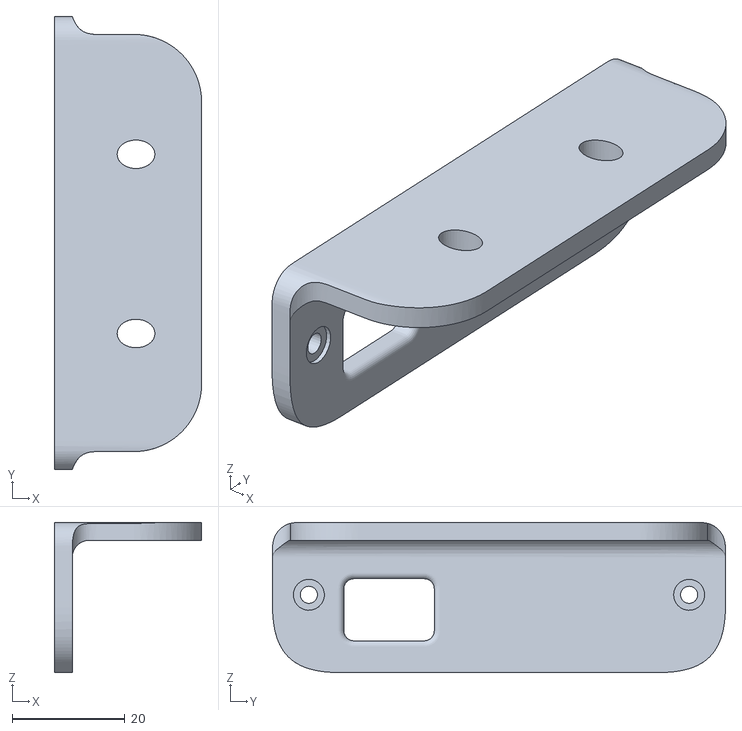
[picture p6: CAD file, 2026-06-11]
CAD/Enclosure/Pulse Pal 3/STL for 3D Printing/PulsePal3 Wing v1_0.stl
26.1 x 80.3 x 26.6

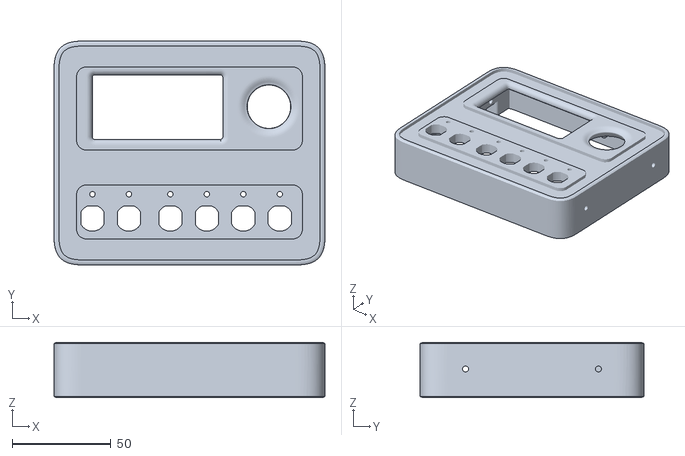
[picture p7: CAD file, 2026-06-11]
CAD/Enclosure/Pulse Pal 3/STL for 3D Printing/PulsePal3 Body v1_0.stl
137.4 x 113.5 x 28.0

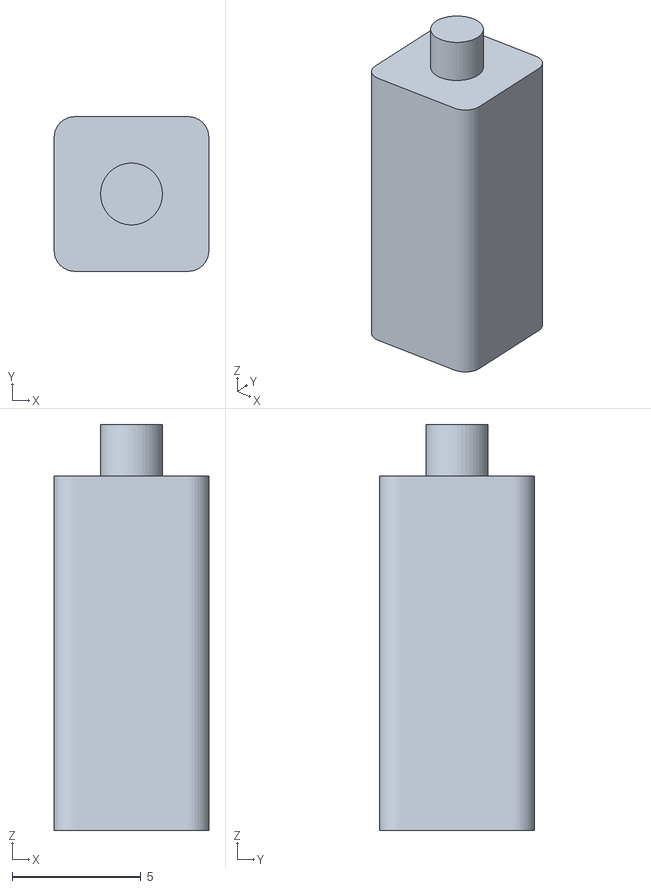
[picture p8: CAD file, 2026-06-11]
CAD/Enclosure/Pulse Pal 3/STL for 3D Printing/PulsePal3 ScreenMount v1_0.stl
6.00 x 6.00 x 15.8

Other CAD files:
CAD/Enclosure/Pulse Pal 1_X/v1.1_ScreenSupport.skp
CAD/Enclosure/Pulse Pal 3/Fusion360 Models/PulsePal3 Assembly v1_0.f3d
CAD/Enclosure/Pulse Pal 3/Fusion360 Models/ScreenMount.f3d

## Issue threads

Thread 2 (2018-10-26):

Rounding of numbers (Phase1Duration)

cskoven, 2018-10-26:
Dear Josh,

I'm playing a bit around with my PulsePal (Gen 2; FW: 2.0.1).

When setting the Phase1Duration manually (by joystick) to 300µs (=0.00030s) and the PulseInterval to 333ms (=0.33300s) in order to obtain 3Hz stimulation, in a burst of 16s - I, instead of the desired 3*16=48 pulses, get 49 pulses. That makes sense, - as there's still room for another pulse.
So I went for the python interface to circumvent this, by writing a loop with a "total number of pulses per burst".

But that introduces some new problems in regards of rounding.
Regardless if I set "myPulsePal.phase1Duration[1] = 0.00030" or "myPulsePal.programOutputChannelParam('phase1Duration', 1, 0.00030)" - the PulsePal reads the Phase1Duration as "0.00025s". And measuring the pulse width on an oscilloscope, the width does seem to be closer to 250µs.

I've also tried approaches with the decimal.Decimal module in python. E.g.
Decimal('300')/Decimal('1000000') => with and without either or both float(Phase1Duration) and round(Phase1Duration,6)...

If I put the following:
myPulsePal.programOutputChannelParam('phase1Duration', 1, 0.000301) -> that is, 301µs, the PulsePal reads "0.00030s", and the width (measured with an oscilloscope) does appear closer to 300µs.

According to your paper regarding the PulsePal (Sanders and Kepecs, 2014) you restricted the shortest configurable pulse duration to 100µs, which is also seen in that it is not possible to adjust the last precision point in the float (by joystick). But then it shouldn't be a problem with 300µs pulses? So I guess it is something about rounding...

When I get the python script to print the values that I assign to the Phase1Duration or InterPhaseInterval (etc.), it does seem to be the right values.

So... I'm probably missing a simple mistake that I make? Or there might be a bug in how these values a registered / assigned on the Arduino?

Hope to hear from you how you would suggest I go forward / circumvent this problem :)

Br,
Christian Skoven

DingLeLe316, 2022-03-21:
Dear @cskoven, could you please paste here your script to check all the parameters you are using?

sanworks, 2023-11-03:
Hi Christian,

This issue is now fixed in commit c0cc326.

Thanks for pointing it out!

-Josh

Closed 2023-11-03.

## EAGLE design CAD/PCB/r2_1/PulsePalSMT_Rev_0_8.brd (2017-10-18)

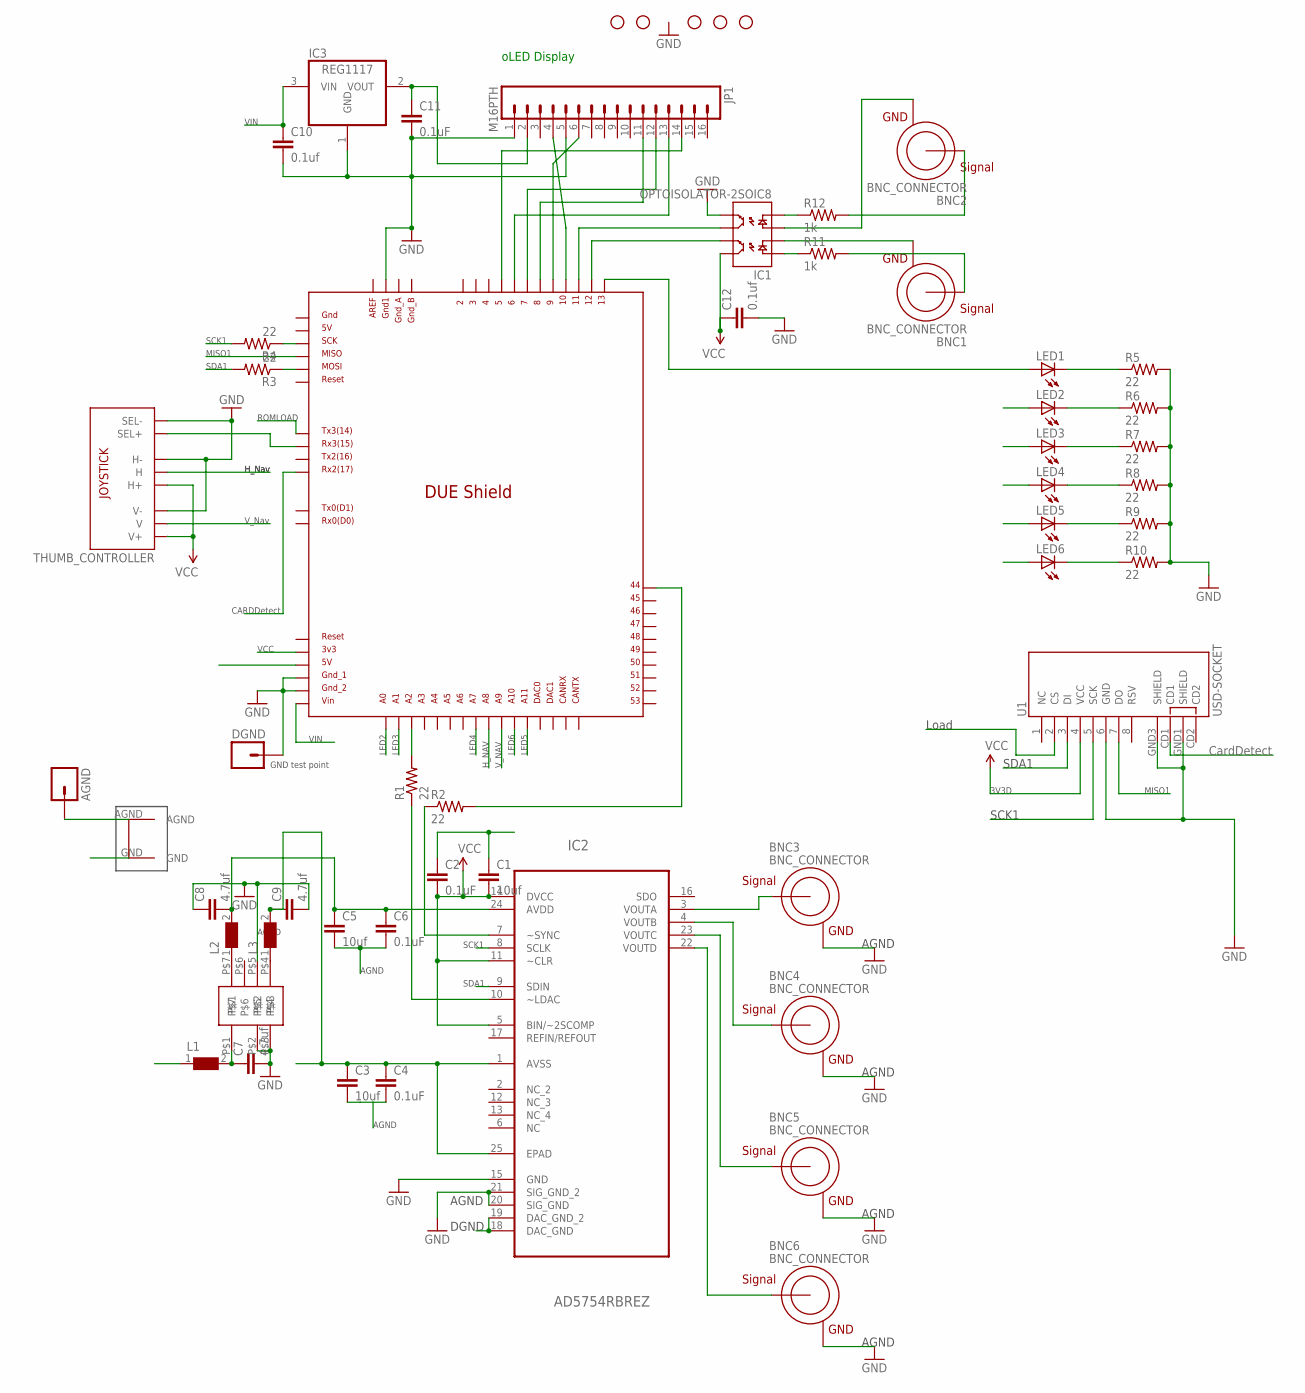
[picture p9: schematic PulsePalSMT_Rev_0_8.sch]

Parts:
AGND: M01PTH; 1X01
ARDUINO: DUE(NORMAL)
BNC1, BNC2, BNC3, BNC4, BNC5, BNC6: BNC_CONNECTOR
C1, C3, C5: 10uf; 1206@1
C2, C4, C6, C11: 0.1uF; 0805
C7, C8, C9: 4.7uf; 1206@1
C10: 0.1uf; 0805
C12: 0.1uf; 1206@1
DGND: M01PTH; 1X01
IC1: OPTOISOLATOR-2SOIC8; SO08-2
IC2: AD5754RBREZ; SOP65P640X120-25N
IC3: REG1117; SOT223
JP1: M16PTH; 1X16
JP2, JP5, JP6, JP8, JP9: STAND-OFF
L1, L2, L3: WE-CBF-742792118_1206; 1206
LED1, LED2, LED3, LED4, LED5, LED6: LEDCHIPLED_1206; CHIPLED_1206
R1, R2, R3, R4, R5, R6, R7, R8, R9, R10: 22; 1206
R11, R12: 1k; 1206
THUMB_CONTROLLER: JOYSTICKPTH; JOYSTICK
U1: USD-SOCKET; MICROSD_1:1
U2: TDK_LAMBDA_5_TO_BI_12_125MA
U$6: GNDPLANESHRT

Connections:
5V: ARDUINO.5V, C1.2, C2.2, IC2.5 (BIN/~2SCOMP), IC2.11 (~CLR), IC2.14 (DVCC), L1.1
AGND: AGND.1, BNC3.GND, BNC4.GND, BNC5.GND, BNC6.GND, C3.2, C4.2, C5.2, C6.2, IC2.15 (GND), IC2.18 (DAC_GND), IC2.19 (DAC_GND_2), IC2.20 (SIG_GND), IC2.21 (SIG_GND_2), U$6.AGND
CARDDETECT: ARDUINO.RX2, U1.CD1
GND: ARDUINO.GND1, ARDUINO.GND_1, ARDUINO.GND_2, C1.1, C2.1, C7.2, C8.1, C9.2, C10.2, C11.2, C12.2, DGND.1, IC1.5 (EM2), IC3.1 (GND), JP1.1, JP1.5, R5.2, R6.2, R7.2, R8.2, R9.2, R10.2, THUMB_CONTROLLER.B2A (SEL-), THUMB_CONTROLLER.H3 (H-), THUMB_CONTROLLER.V3 (V-), U1.6 (GND), U1.GND1 (SHIELD), U1.GND3 (SHIELD), U2.P$2, U2.P$3, U2.P$5, U$6.GND
H_NAV: ARDUINO.A8, THUMB_CONTROLLER.H2 (H)
LED2: ARDUINO.A0, LED2.A
LED3: ARDUINO.A1, LED3.A
LED4: ARDUINO.A7, LED4.A
LED5: ARDUINO.A11, LED5.A
LED6: ARDUINO.A10, LED6.A
MISO1: ARDUINO.MISO_ICSP, U1.7 (DO)
unnamed: L2.1, U2.P$7
unnamed: L3.1, U2.P$4
unnamed: BNC3.SIGNAL, IC2.3 (VOUTA)
unnamed: BNC4.SIGNAL, IC2.4 (VOUTB)
unnamed: BNC5.SIGNAL, IC2.23 (VOUTC)
unnamed: BNC6.SIGNAL, IC2.22 (VOUTD)
unnamed: BNC1.GND, IC1.2 (C1)
unnamed: BNC1.SIGNAL, R11.2
unnamed: BNC2.GND, IC1.3 (A2)
unnamed: BNC2.SIGNAL, R12.2
unnamed: ARDUINO.SCK_ICSP, R4.1
unnamed: ARDUINO.MOSI_ICSP, R3.1
unnamed: ARDUINO.44, R2.2
unnamed: ARDUINO.A2, R1.2
unnamed: IC2.7 (~SYNC), R2.1
unnamed: IC2.10 (~LDAC), R1.1
unnamed: ARDUINO.RX3, THUMB_CONTROLLER.B1A (SEL+)
unnamed: ARDUINO.11, IC1.6 (CL2)
unnamed: C11.1, IC3.2 (VOUT), JP1.2
unnamed: LED1.C, R5.1
unnamed: LED2.C, R6.1
unnamed: LED3.C, R7.1
unnamed: LED4.C, R8.1
unnamed: LED5.C, R9.1
unnamed: LED6.C, R10.1
unnamed: IC1.1 (A1), R11.1
unnamed: IC1.4 (C2), R12.1
unnamed: ARDUINO.12, IC1.7 (EM1)
unnamed: ARDUINO.5, JP1.14
unnamed: ARDUINO.13, LED1.A
unnamed: ARDUINO.10, JP1.4
unnamed: ARDUINO.9, JP1.6
unnamed: ARDUINO.8, JP1.11
unnamed: ARDUINO.7, JP1.12
unnamed: ARDUINO.6, JP1.13
unnamed: C5.1, C6.1, C8.2, IC2.24 (AVDD), L2.2
unnamed: C3.1, C4.1, C9.1, IC2.1 (AVSS), IC2.25 (EPAD), L3.2
unnamed: C7.1, L1.2, U2.P$1
ROMLOAD: ARDUINO.TX3, U1.2 (CS)
SCK1: IC2.8 (SCLK), R4.2, U1.5 (SCK)
SDA1: IC2.9 (SDIN), R3.2, U1.3 (DI)
VCC: ARDUINO.3V3, C12.1, IC1.8 (CL1), THUMB_CONTROLLER.H1 (H+), THUMB_CONTROLLER.V1 (V+), U1.4 (VCC)
VIN: ARDUINO.VIN, C10.1, IC3.3 (VIN)
V_NAV: ARDUINO.A9, THUMB_CONTROLLER.V2 (V)

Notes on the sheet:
oLED Display
AGND
SCK1
SDA1
DGND
VCC
ROMLOAD
LED2
LED3
LED4
LED5
LED6
GND test point
H_Nav
V_Nav
MISO1
H_NAV
V_NAV
VIN
3V3D
Load
CardDetect
CARDDetect

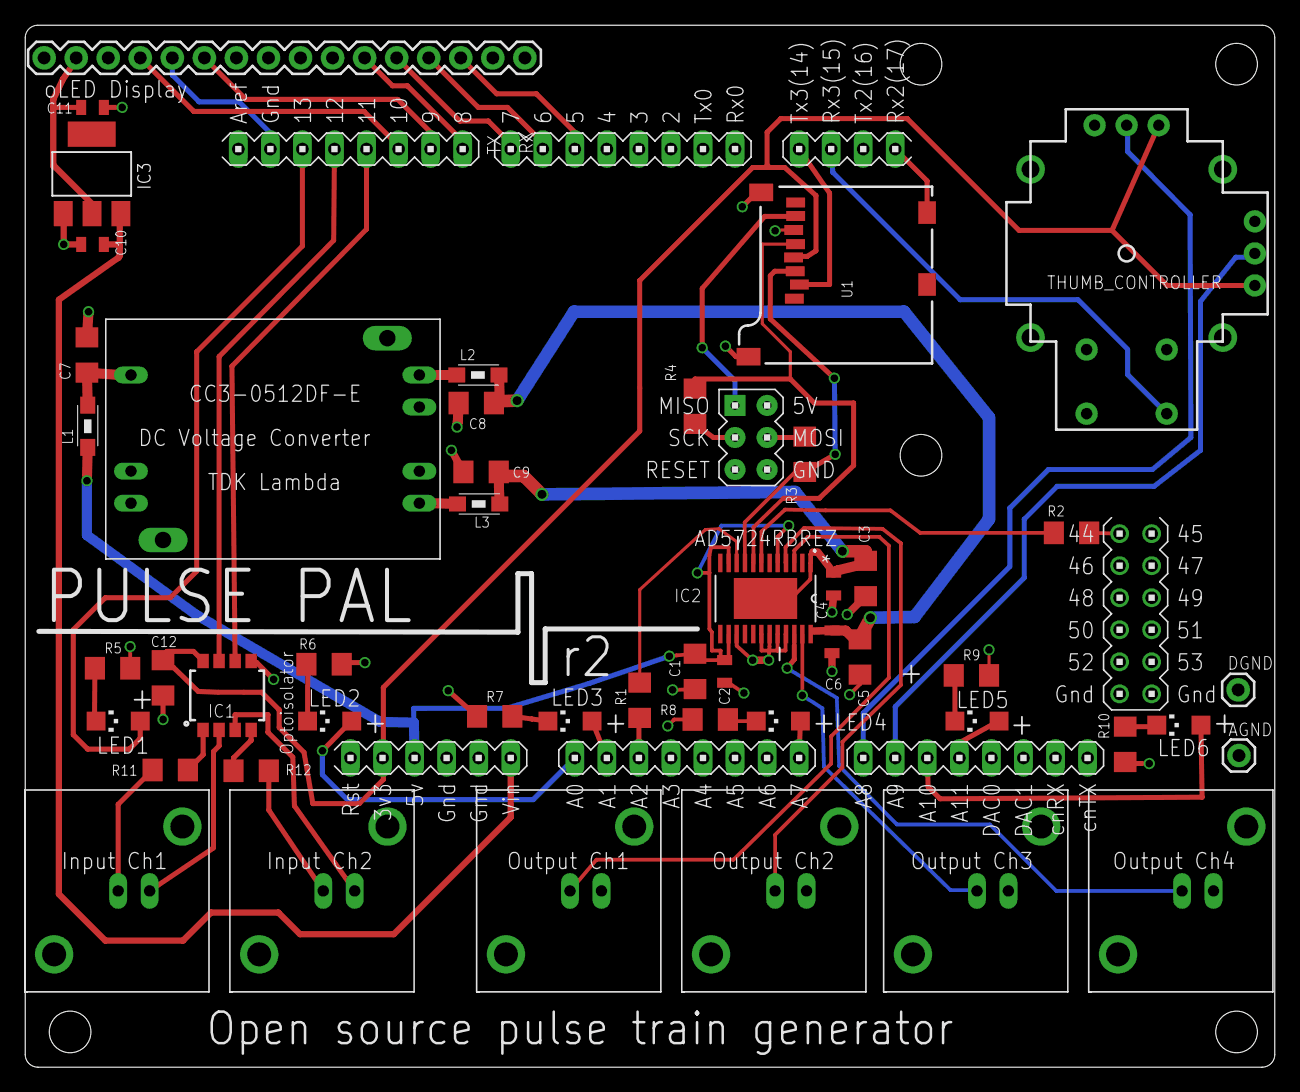
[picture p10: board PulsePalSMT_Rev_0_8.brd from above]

Board: 4 copper layers, 99.0 x 82.6 mm, 55 parts (0 on the bottom side), 55 nets.

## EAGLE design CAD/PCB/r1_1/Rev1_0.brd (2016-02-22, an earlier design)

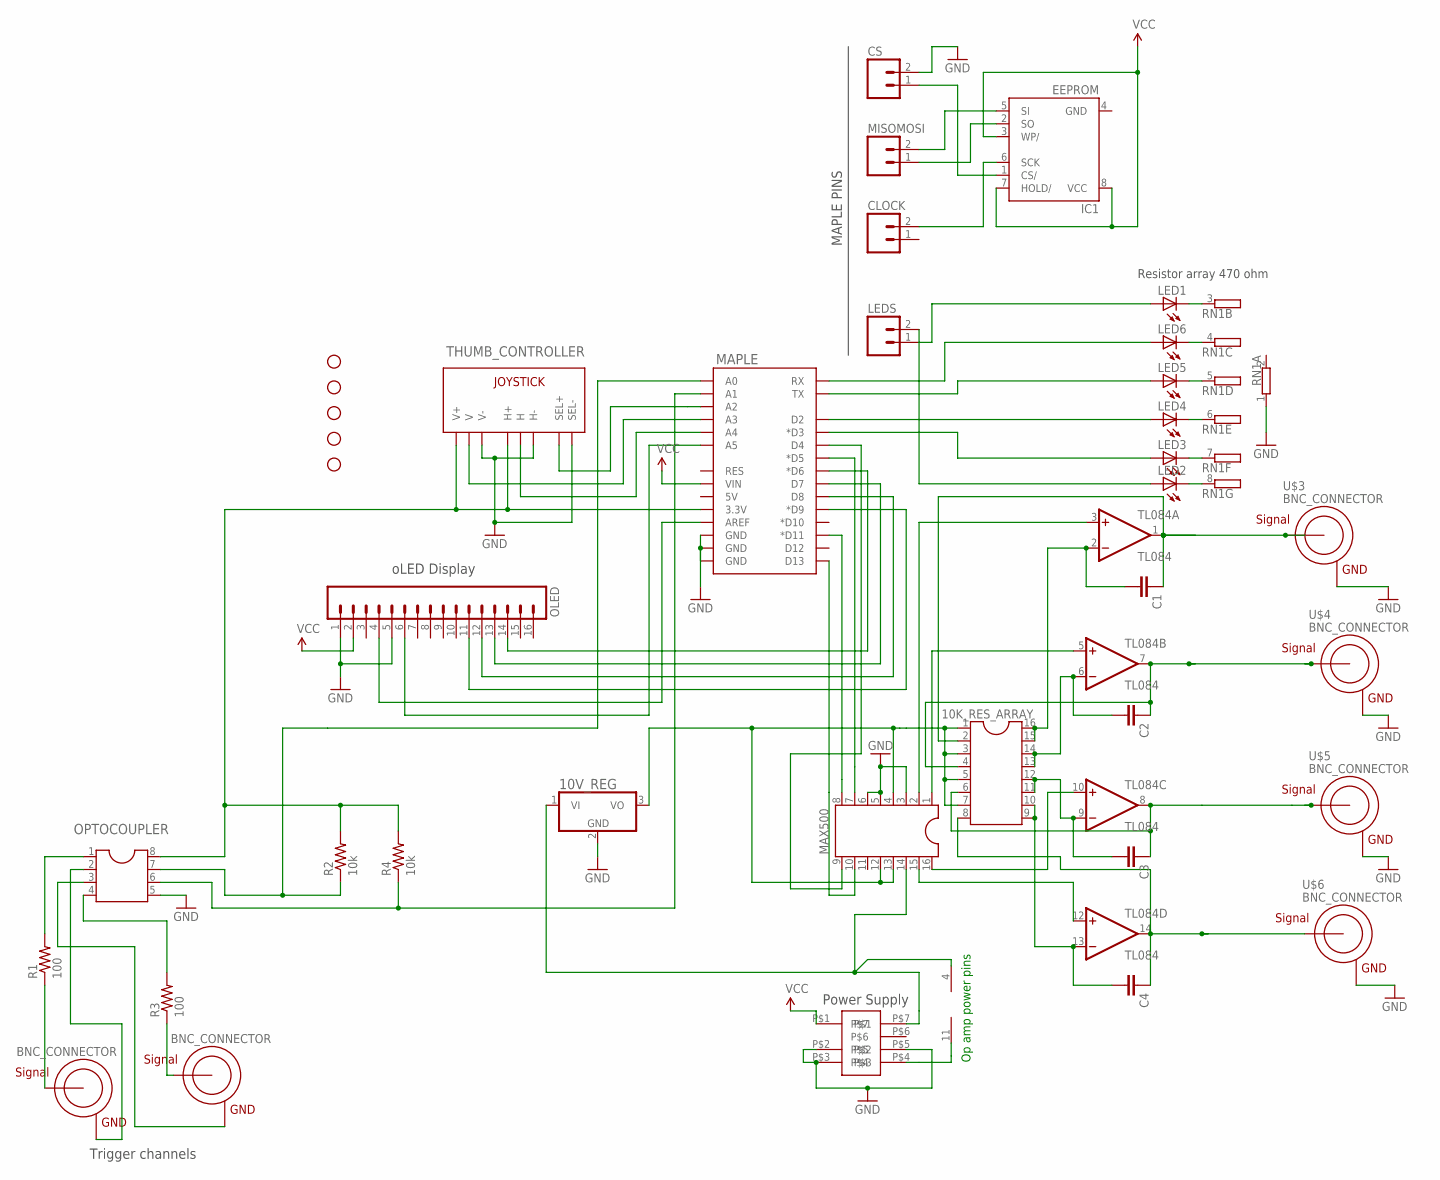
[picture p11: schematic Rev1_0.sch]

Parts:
10K_RES_ARRAY: DIL16
10V_REG: 7805T; TO220H
C1, C2, C3, C4: CAPPTH; CAP-PTH-SMALL
CLOCK: M02PTH; 1X02
CS: M02PTH; 1X02
IC1: EEPROM; DIL08
JP2, JP5, JP6, JP8, JP9: STAND-OFF
LED1, LED2, LED3, LED4, LED5, LED6: LED3MM
LEDS: M02PTH; 1X02
MAPLE: ARDUINO_SHIELDNOHOLESORLABELS; DUEMILANOVE_SHIELD_NOHOLES_NOLABELS
MAX500: DIL16
MISOMOSI: M02PTH; 1X02
OLED: M16PTH; 1X16
OPTOCOUPLER: DIL8; DIL08
R1, R3: 100; AXIAL-0.3
R2, R4: 10k; AXIAL-0.3
RN1: GE07R; SIL8
THUMB_CONTROLLER: JOYSTICKPTH; JOYSTICK
TL084: TL084; DIL14
U$1, U$2, U$3, U$4, U$5, U$6: BNC_CONNECTOR
U$8: TDK_LAMBDA_5_TO_BI_12_125MA

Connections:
GND: 10V_REG.2 (GND), CS.2, IC1.4 (GND), MAPLE.GND@0 (GND), MAPLE.GND@1 (GND), MAPLE.GND@2 (GND), MAX500.3, MAX500.5, MAX500.6, OLED.1, OLED.5, OPTOCOUPLER.5, RN1.1, THUMB_CONTROLLER.B2A (SEL-), THUMB_CONTROLLER.H3 (H-), THUMB_CONTROLLER.V3 (V-), U$3.GND, U$4.GND, U$5.GND, U$6.GND, U$8.P$2, U$8.P$3, U$8.P$5
unnamed: LED6.A, MAPLE.RX
unnamed: LED5.A, MAPLE.TX
unnamed: LED4.A, MAPLE.D2
unnamed: LED3.A, MAPLE.D3 (*D3)
unnamed: MAPLE.D11 (*D11), MAX500.8
unnamed: MAPLE.D13, MAX500.10
unnamed: MAPLE.AREF, OLED.4
unnamed: MAPLE.D4, MAX500.9
unnamed: MAPLE.D5 (*D5), MAX500.7
unnamed: MAPLE.D6 (*D6), OLED.14
unnamed: MAPLE.D7, OLED.13
unnamed: MAPLE.D8, OLED.12
unnamed: MAPLE.D9 (*D9), OLED.11
unnamed: MAPLE.A5, OLED.6
unnamed: MAPLE.A4, THUMB_CONTROLLER.H2 (H)
unnamed: MAPLE.A3, THUMB_CONTROLLER.V2 (V)
unnamed: MAPLE.A2, THUMB_CONTROLLER.B1A (SEL+)
unnamed: R1.P$1 (1), U$1.SIGNAL
unnamed: MAPLE.A0, OPTOCOUPLER.7, R2.P$1 (1)
unnamed: R3.P$1 (1), U$2.SIGNAL
unnamed: MAPLE.A1, OPTOCOUPLER.6, R4.P$1 (1)
unnamed: TL084.11 (V-), U$8.P$4
unnamed: MAX500.2, TL084.3 (+IN)
unnamed: MAX500.1, TL084.5 (+IN)
unnamed: 10V_REG.1 (VI), MAX500.14, TL084.4 (V+), U$8.P$7
unnamed: 10K_RES_ARRAY.1, 10K_RES_ARRAY.3, 10K_RES_ARRAY.5, 10K_RES_ARRAY.7, 10V_REG.3 (VO), MAX500.4, MAX500.12, MAX500.13
unnamed: MAX500.16, TL084.10 (+IN)
unnamed: MAX500.15, TL084.12 (+IN)
unnamed: 10K_RES_ARRAY.2, C1.1, TL084.1 (OUT), U$3.SIGNAL
unnamed: 10K_RES_ARRAY.4, C2.1, TL084.7 (OUT), U$4.SIGNAL
unnamed: 10K_RES_ARRAY.6, C3.1, TL084.8 (OUT), U$5.SIGNAL
unnamed: 10K_RES_ARRAY.8, C4.1, TL084.14 (OUT), U$6.SIGNAL
unnamed: LED1.A, LEDS.1
unnamed: LED2.A, LEDS.2
unnamed: LED2.K (C), RN1.8 (2)
unnamed: LED3.K (C), RN1.7 (2)
unnamed: LED4.K (C), RN1.6 (2)
unnamed: LED5.K (C), RN1.5 (2)
unnamed: LED6.K (C), RN1.4 (2)
unnamed: 10K_RES_ARRAY.15, 10K_RES_ARRAY.16, C1.2, TL084.2 (-IN)
unnamed: 10K_RES_ARRAY.13, 10K_RES_ARRAY.14, C2.2, TL084.6 (-IN)
unnamed: 10K_RES_ARRAY.11, 10K_RES_ARRAY.12, C3.2, TL084.9 (-IN)
unnamed: 10K_RES_ARRAY.9, 10K_RES_ARRAY.10, C4.2, TL084.13 (-IN)
unnamed: LED1.K (C), RN1.3 (2)
unnamed: OPTOCOUPLER.1, R1.P$2 (2)
unnamed: CS.1, IC1.1 (CS/)
unnamed: IC1.5 (SI), MISOMOSI.2
unnamed: IC1.2 (SO), MISOMOSI.1
unnamed: CLOCK.2, IC1.6 (SCK)
unnamed: OPTOCOUPLER.2, U$1.GND
unnamed: OPTOCOUPLER.4, R3.P$2 (2)
unnamed: OPTOCOUPLER.3, U$2.GND
unnamed: MAPLE.3.3V, OPTOCOUPLER.8, R2.P$2 (2), R4.P$2 (2), THUMB_CONTROLLER.H1 (H+), THUMB_CONTROLLER.V1 (V+)
VCC: IC1.3 (WP/), IC1.7 (HOLD/), IC1.8 (VCC), MAPLE.VIN, OLED.2, U$8.P$1

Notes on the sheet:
oLED Display
Power Supply
Op amp power pins
MAPLE PINS
Trigger channels
Resistor array 470 ohm

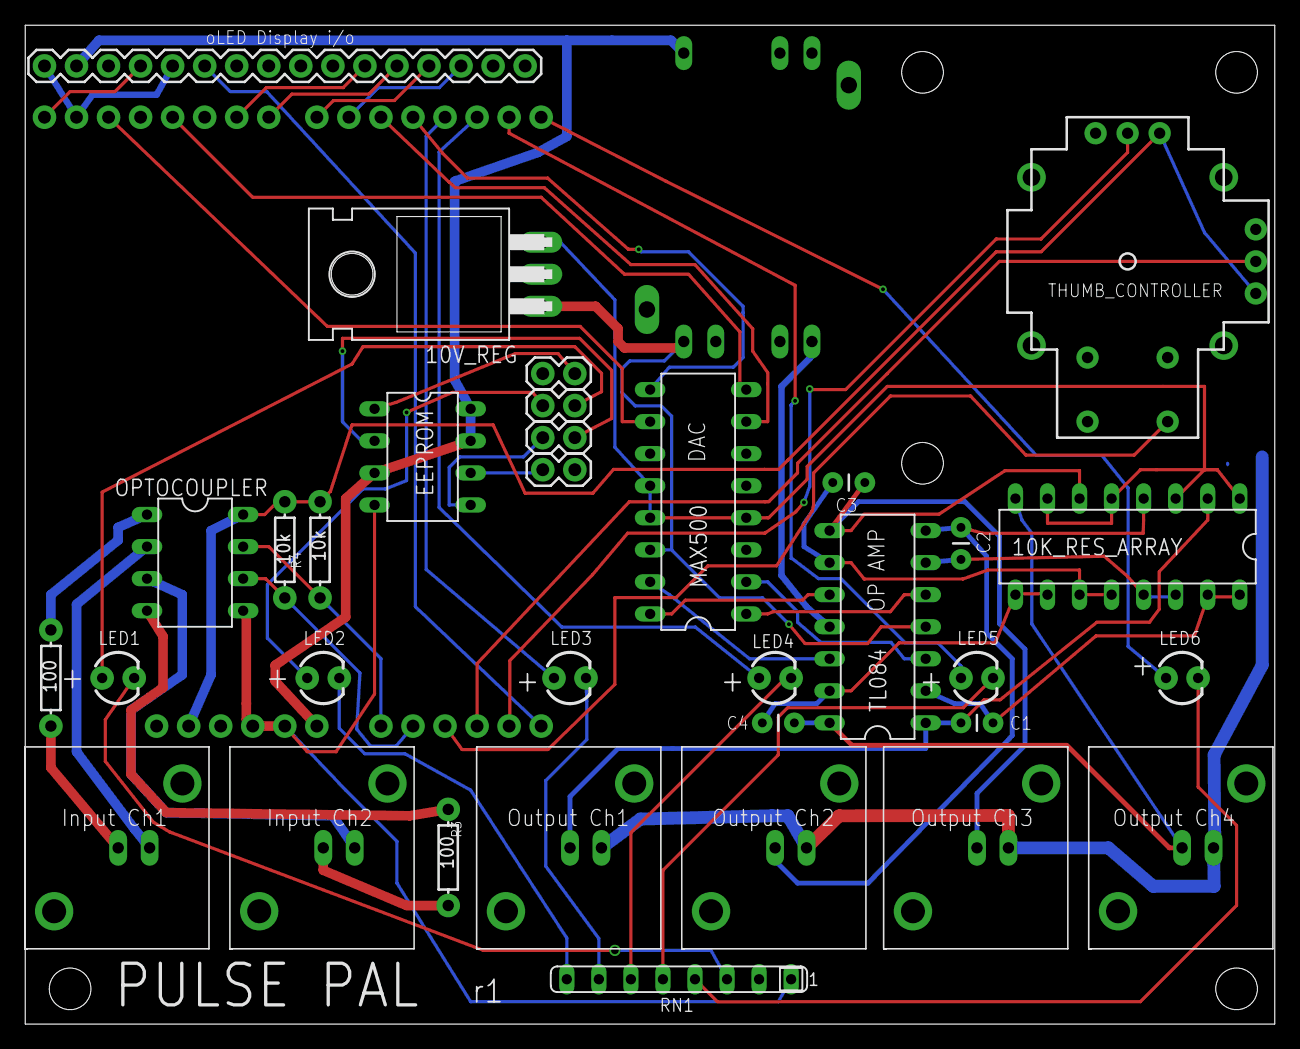
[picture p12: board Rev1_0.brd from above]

Board: 4 copper layers, 99.0 x 79.2 mm, 40 parts (1 on the bottom side), 55 nets.

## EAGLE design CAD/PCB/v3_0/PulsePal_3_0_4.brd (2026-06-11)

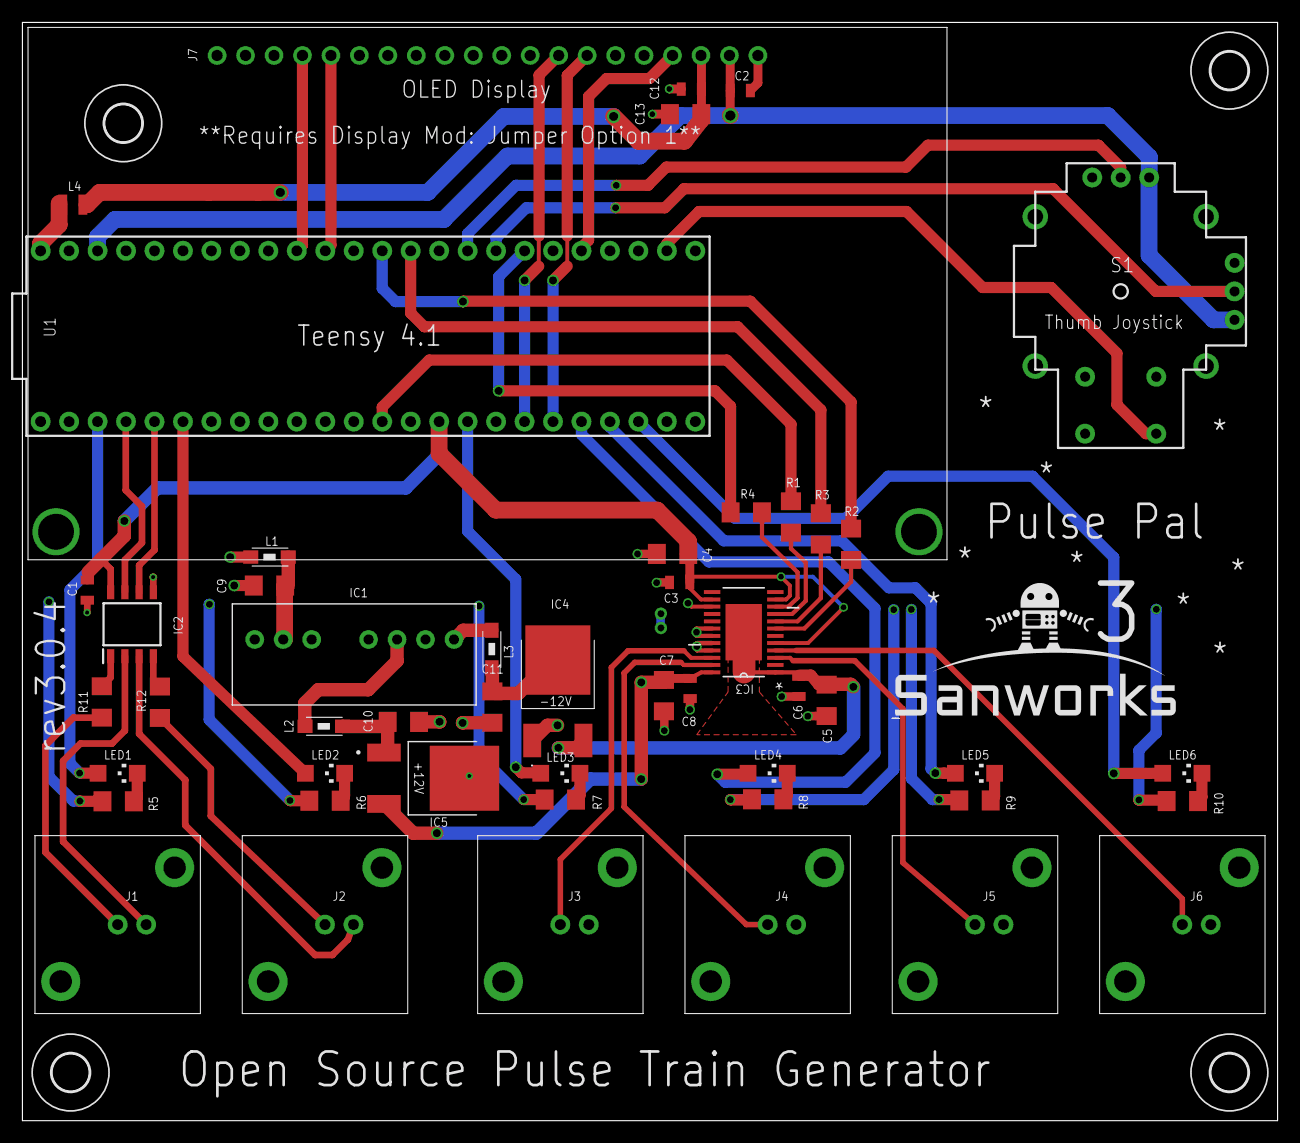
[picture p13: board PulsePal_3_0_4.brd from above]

Board: 4 copper layers, 112.0 x 98.0 mm, 55 parts (0 on the bottom side), 52 nets.

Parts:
C1, C2, C3, C6, C8, C12: 0.1uF; 0805
C4, C5, C7, C13: 10uf; 1206@1
C9, C10, C11: 4.7uf; 1206@1
H1, H2, H3, H4: MOUNT-HOLE3.3; 3,3
IC1: RS3-0515D
IC2: ACPL-064L-500E; SOIC127P599X330-8N
IC3: AD5754RBREZ; SOP65P640X120-25N
IC4: MC79M12CDTRKG; NVD5117PLT4GVF01
IC5: MC78M12CDTRKG; VREG_MC78M12CDTRKG
J1, J2, J3, J4, J5, J6: 5227673-1; 52276731
J7: NHD-2.7-12864WDW3
L1, L2, L3: 1206
L4: 10μH; 0806
LED1, LED2, LED3, LED4, LED5, LED6: CHIPLED_1206
R1, R2, R3, R4: 22; 1206
R5, R6, R7, R8, R9, R10: 75; 1206
R11, R12: 1k; 1206
S1: JOYSTICK
U1: TEENSY_3.6_DIL
U$2: SANWORKS_LOGO
U$6: GNDPLANESHRT

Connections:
3V3: C1.2, C2.1, C3.2, C4.2, IC2.8, IC3.5, IC3.11, IC3.14, J7.P$19, S1.H1, S1.V1, U1.3.3V, U1.3.3V3
5V: L1.1, L4.1, U1.VIN
AGND: C5.2, C6.2, C7.2, C8.2, C10.1, C11.2, IC1.COM, IC3.18, IC3.19, IC3.20, IC3.21, IC4.1, IC5.2_4, J3.GND, J4.GND, J5.GND, J6.GND, U1.AGND, U$6.AGND
CS1: J7.P$4, U1.17/A3
D/C: J7.P$17, U1.37/A18
GND: C1.1, C2.2, C3.1, C4.1, C9.2, C12.2, C13.2, IC1.-VIN, IC2.5, IC3.15, J7.P$1, J7.P$2, J7.P$7, J7.P$8, J7.P$9, J7.P$10, J7.P$11, J7.P$15, J7.P$16, J7.P$20, R5.2, R6.2, R7.2, R8.2, R9.2, R10.2, S1.B2A, S1.H3, S1.V3, U1.25, U1.GND, U1.GND1, U$6.GND
LDAC: IC3.10, R4.1
LED1: LED1.A, U1.1
LED2: LED2.A, U1.4
LED3: LED3.A, U1.24
LED4: LED4.A, U1.28
LED5: LED5.A, U1.29
LED6: LED6.A, U1.30
MOSI1: J7.P$13, U1.26
unnamed: IC2.1, R11.2
unnamed: J1.SIG, R11.1
unnamed: IC2.4, R12.2
unnamed: J2.SIG, R12.1
unnamed: IC2.2, J1.GND
unnamed: IC2.3, J2.GND
unnamed: LED1.C, R5.1
unnamed: LED2.C, R6.1
unnamed: IC3.3, J5.SIG
unnamed: IC3.4, J6.SIG
unnamed: IC3.23, J4.SIG
unnamed: IC3.22, J3.SIG
unnamed: R1.2, U1.11
unnamed: R3.2, U1.13
unnamed: IC1.-VOUT, L3.1
unnamed: IC1.+VOUT, L2.1
unnamed: R2.2, U1.14/A0
unnamed: R4.2, U1.39/A20
unnamed: LED3.C, R7.1
unnamed: LED4.C, R8.1
unnamed: LED5.C, R9.1
unnamed: LED6.C, R10.1
unnamed: C10.2, IC5.1, L2.2
unnamed: C11.1, IC4.2, L3.2
unnamed: C12.1, C13.1, J7.P$18, L4.2
unnamed: C9.1, IC1.+VIN, L1.2
NAV_B: S1.B1A, U1.34/A15
NAV_H: S1.H2, U1.A22
NAV_V: S1.V2, U1.A21
RST: J7.P$5, U1.16/A2
SCK0: IC3.8, R3.1
SCK1: J7.P$14, U1.27
SDA0: IC3.9, R1.1
SYNC: IC3.7, R2.1
TRIG1: IC2.7, U1.2
TRIG2: IC2.6, U1.3
VDD: C7.1, C8.1, IC3.24, IC5.3
VSS: C5.1, C6.1, IC3.1, IC3.25, IC4.3

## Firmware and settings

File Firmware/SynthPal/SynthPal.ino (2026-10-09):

/*
----------------------------------------------------------------------------

This file is part of the Pulse Pal Project
Copyright (C) 2026 Sanworks LLC, Rochester, NY, USA

----------------------------------------------------------------------------

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
*/

// SYNTH PAL FIRMWARE for Pulse Pal 3 hardware
//
// Synth Pal turns a Pulse Pal 3 into a four channel waveform synthesizer. Each output channel plays a sine, triangle,
// square or sawtooth wave, with its own amplitude (peak to peak), mean voltage, resting voltage (the voltage between
// playbacks) and play duration, when it is triggered: by a TTL edge on a trigger channel, by a command from the PC, or
// from the thumb joystick menu. A channel can instead play a fixed voltage, its amplitude, for its play duration. Linear
// on and off ramps can fade each channel in from its resting voltage, and back to it.
// One frequency, 1Hz to 20kHz in steps of 0.01Hz, applies to all four channels.
// Samples are computed as they play, at a sampling rate that is a multiple of the frequency, so that every cycle is
// rendered the same way. The DAC's output range is chosen for each channel, to give its waveform the finest steps.
// The USB protocol is documented in PROTOCOL.md in this folder, and AGENTS.md lists the rules for changing this code.
//
// ** DEPENDENCIES YOU NEED TO INSTALL FIRST **
// Board: Teensy 4.1, from Teensyduino. Library: U8g2_Arduino, developed by Oliver Kraus (Thanks Oliver!!), from the
// Arduino library manager (verified with v2.36.19).
//
// CODE MAP
// This sketch is split into tabs. Arduino joins them into a single file before compiling (this file first, then the
// others in alphabetical order), so all tabs share the constants and global variables defined in this file.
//   SynthPal.ino     Build configuration, pin map, named constants, global variables, setup() and loop()
//   Playback.ino     The sample clock interrupt handler(), waveform synthesis, the trigger inputs, and starting and
//                    stopping channels. Start here for timing questions: "How playback works" is at the top.
//   Settings.ino     The frequency and the output channel settings: limits, output ranges, and handing new settings
//                    to the playback interrupts
//   USBOps.ino       Commands from the PC, processUSBCommands()
//   Menu.ino         Thumb joystick menu, with a map of its options, and the value editors
//   Display.ino      Screen output, screen saver and splash screen
//   HardwareIO.ino   DAC writes, output ranges, the sample clock's timer and software reset
// Supporting classes: ArCOM (USB serial data types), LiquidCrystal_U8G2 (screen). Both are copies of the ones in
// /Firmware/PulsePal3.

#define FIRMWARE_VERSION 1

// SETUP MACRO TO COMPILE FOR TARGET DEVICE:
#ifndef PIN_MAP_VERSION
  #define PIN_MAP_VERSION 1 // Hardware pin map. Use 0 for Pulse Pal PCB version < 3.0.4 and 1 for 3.0.5+
#endif

#if (PIN_MAP_VERSION < 0) || (PIN_MAP_VERSION > 1)
#error Error! PIN_MAP_VERSION must be either 0 or 1
#endif

#if !defined(ARDUINO_TEENSY41)
#error Synth Pal runs on Pulse Pal 3 hardware only. Select Tools > Board > Teensy 4.1.
#endif

#define HARDWARE_VERSION 3 // Pulse Pal hardware version. Synth Pal runs on Pulse Pal 3 only. ArCOM.h reads this.

#include <SPI.h>
#include <EEPROM.h>
#include <U8g2lib.h>
// The screen is on the Teensy's second SPI bus. u8g2 compiles its second-bus driver only when the core defines
// SPI_INTERFACES_COUNT > 1, which Teensyduino does. If that ever stops being true the driver becomes an empty stub:
// the sketch still builds, and the screen stays dark. Stop the build instead.
#if !defined(U8X8_HAVE_2ND_HW_SPI)
  #error u8g2 has no second hardware SPI. The Pulse Pal 3 screen will not work.
#endif
#include "ArCOM.h"
#include "LiquidCrystal_U8G2.h"
#include "GFXData.h"

#define STRINGIFY(x) #x // This and the following line enable conversion of macros to strings (e.g. for displaying firmware version)
#define TOSTRING(x) STRINGIFY(x)

// ---------------------------------------------------------------------------------------------------------------
// Named constants. The numeric values of the op codes, waveforms, trigger modes and output ranges are part of the USB
// protocol (PROTOCOL.md), so they must never be renumbered.
// ---------------------------------------------------------------------------------------------------------------

// USB op codes. Every command from the PC is: OpMenuByte (213), op code, then op-specific data. Ops 72, 81, 89 and 99
// are those of Pulse Pal firmware. The others are ASCII letters, as in Wave Pal.
enum OpCode {
  OP_HANDSHAKE = 72,                  // Returns HANDSHAKE_REPLY and the firmware version
  OP_DISCONNECT = 81,                 // The client is closing: stop playback, and show the device's own name again
  OP_SET_CLIENT_NAME = 89,            // Set the 6-character client name shown on the top screen, as "NAME Connected"
  OP_SET_SCREEN_SAVER = 99,           // Switch the screen saver on or off, and set its timeout (stored in EEPROM)
  OP_HARDWARE_INFO = 'N',             // 78. Returns the hardware properties and the limits of the settings
  OP_SET_FREQUENCY = 'F',             // 70. Frequency of all output channels, in hundredths of a Hz
  OP_SET_WAVEFORM = 'W',              // 87. Waveform of each output channel. See enum WaveformValue
  OP_SET_AMPLITUDE = 'A',             // 65. Amplitude of each output channel, in microvolts: peak to peak, or the voltage
                                      // of a fixed voltage
  OP_SET_RESTING_VOLTAGE = 'V',       // 86. Resting voltage of each output channel, in microvolts
  OP_SET_MEAN_VOLTAGE = 'M',          // 77. Mean voltage of each output channel's waveform, in microvolts
  OP_SET_PLAY_DURATION = 'D',         // 68. Play duration of each output channel, in microseconds. 0 = until stopped
  OP_SET_ON_RAMP_DURATION = 'B',      // 66. On ramp of each output channel, at the Beginning of playback, in microseconds
  OP_SET_OFF_RAMP_DURATION = 'E',     // 69. Off ramp of each output channel, at the End of playback, in microseconds
  OP_SET_TRIGGER_LINKS = 'I',         // 73. Links from the trigger channels to the output channels
  OP_SET_TRIGGER_MODE = 'T',          // 84. Trigger mode of each trigger channel. See enum TriggerModeValue
  OP_SET_ALL_SETTINGS = 'U',          // 85. Every setting at once. While a trigger channel is in param sync mode, stored
                                      // for its next rising edge instead (see "Param sync" in Playback.ino)
  OP_GET_ALL_SETTINGS = 'R',          // 82. Returns every setting the device plays, in op 85's layout
  OP_PLAY = 'P',                      // 80. Soft-trigger output channels (1 bit per channel)
  OP_STOP = 'X',                      // 88. Stop output channels (1 bit per channel)
  OP_GET_STATUS = 'G',                // 71. Returns the playback state
  OP_GET_PLAYBACK_CHECKSUMS = 'Z'     // 90. For testing: samples played since each channel started, and their sum
};
#define HANDSHAKE_REPLY 'S' // 83. Pulse Pal firmware replies 'K' (75) to op 72 and Wave Pal 'W' (87), so clients can tell
                            // the three apart

// Values of waveform[]. The shape of one cycle, as it starts at a trigger: see unitWaveform() in Playback.ino. The
// codes are fixed (see PROTOCOL.md): add new waveforms at the end.
enum WaveformValue {
  WAVEFORM_SINE = 0,                  // Starts at the resting voltage, rising
  WAVEFORM_TRIANGLE = 1,              // Starts at the resting voltage, rising
  WAVEFORM_SQUARE = 2,                // High for the first half of each cycle, low for the second
  WAVEFORM_SAWTOOTH = 3,              // Rises from its lowest voltage to its highest, then falls back at the cycle's end
  WAVEFORM_FIXED_VOLTAGE = 4,         // Not periodic: the output steps to the amplitude, a voltage (-10V to 10V), for the
                                      // play duration. See isValidOutputLevel() in Settings.ino.
  WAVEFORM_WHITE_NOISE = 5            // Not periodic: a new random voltage on every sample, uniform over the peak to
                                      // peak amplitude around the mean voltage. See noiseSample() in Playback.ino.
};
#define MAX_WAVEFORM WAVEFORM_WHITE_NOISE

// Values of TriggerMode[], one per trigger channel. These are Pulse Pal's trigger modes, with the same values.
enum TriggerModeValue {
  TRIGGER_MODE_NORMAL = 0,            // A rising edge starts the linked output channels. It is ignored by channels that play.
  TRIGGER_MODE_TOGGLE = 1,            // A rising edge starts the linked output channels, or stops those that play
  TRIGGER_MODE_GATED = 2,             // A rising edge starts the linked output channels, and a falling edge stops them
  TRIGGER_MODE_PARAM_SYNC = 3         // A rising edge loads the settings op 85 stored. It starts and stops nothing.
};
#define MAX_TRIGGER_MODE TRIGGER_MODE_PARAM_SYNC

// The AD5754R's output ranges that Synth Pal uses, one per output channel, chosen from the channel's settings by
// outputRangeFor() in Settings.ino: the first range in this order that holds the whole waveform. The 10.8V ranges are not
// used: every voltage within +/-10V fits one of these, with finer steps.
enum OutputRange {
  RANGE_0_TO_5V = 0,                  // 76uV steps
  RANGE_0_TO_10V = 1,                 // 153uV steps
  RANGE_PLUS_MINUS_5V = 2,            // 153uV steps
  RANGE_PLUS_MINUS_10V = 3            // 305uV steps. Pulse Pal's range, in which the zero code calibration was measured
};
#define N_OUTPUT_RANGES 4
const byte dacRangeCodes[N_OUTPUT_RANGES] = {0, 1, 3, 4}; // The AD5754R's output range select code for each range
const int32_t rangeMinMicrovolts[N_OUTPUT_RANGES] = {0, 0, -5000000, -10000000}; // Voltage of DAC code 0
const int32_t rangeMaxMicrovolts[N_OUTPUT_RANGES] = {5000000, 10000000, 5000000, 10000000}; // Voltage of code 65536

// Values of inMenu, the current level of the thumb joystick menu. See the menu map in Menu.ino.
enum MenuLevel {
  MENU_TOP = 0,                       // "Synth Pal v3.0 / Click for menu"
  MENU_CHANNEL_LIST = 1,              // Scroll through the channels, frequency, screen saver, device info, reset and exit
  MENU_OUTPUT_CHANNEL = 2,            // Settings of one output channel
  MENU_TRIGGER_CHANNEL = 3            // Settings of one trigger channel
};

// Values of SelectedChannel, the item selected in MENU_CHANNEL_LIST. Items 1-4 are the output channels, and 5-6 the
// trigger channels.
enum ChannelListItem {
  MENU_ITEM_FREQUENCY = 7,
  MENU_ITEM_SCREEN_SAVER = 8,
  MENU_ITEM_DEVICE_INFO = 9,
  MENU_ITEM_RESET = 10,
  MENU_ITEM_EXIT = 11                 // The last item
};

// Values of SelectedAction, the item selected in MENU_OUTPUT_CHANNEL
enum OutputChannelAction {
  MENU_ACTION_TRIGGER = 1,            // Play the channel, or stop it while it plays
  MENU_ACTION_WAVEFORM = 2,
  MENU_ACTION_AMPLITUDE = 3,
  MENU_ACTION_MEAN_VOLTAGE = 4,
  MENU_ACTION_RESTING_VOLTAGE = 5,
  MENU_ACTION_PLAY_DURATION = 6,
  MENU_ACTION_ON_RAMP = 7,
  MENU_ACTION_OFF_RAMP = 8,
  MENU_ACTION_LINK_TRIGGER1 = 9,
  MENU_ACTION_LINK_TRIGGER2 = 10,
  MENU_ACTION_EXIT = 11               // The last item
};

// Values of rampStage[], each playing channel's place in its envelope. See "Ramps" in Playback.ino.
enum RampStage {
  STAGE_ON_RAMP = 0,                  // Fading in from the resting voltage. Every start begins here, even with no on ramp
  STAGE_HOLD = 1,                     // Full amplitude around the mean voltage, for the play duration
  STAGE_OFF_RAMP = 2                  // Fading back to the resting voltage
};

// Values of SelectedInputAction, the item selected in MENU_TRIGGER_CHANNEL
enum TriggerChannelAction {
  MENU_INPUT_ACTION_TRIGGER = 1,      // Act as a rising edge on the trigger channel
  MENU_INPUT_ACTION_MODE = 2,
  MENU_INPUT_ACTION_EXIT = 3          // The last item
};

#define N_CHANNELS 4
#define ALL_CHANNELS 0x0F // Channel bits for output channels 1-4

// Limits of the settings. Op 78 reports them.
#define MIN_FREQUENCY_CENTIHZ 100 // 1Hz
#define MAX_FREQUENCY_CENTIHZ 2000000 // 20kHz
#define MAX_AMPLITUDE_MICROVOLTS 20000000 // 20V peak to peak
#define MAX_VOLTAGE_MICROVOLTS 10000000 // Every voltage on an output stays within +/-10V
#define MAX_PLAY_DURATION_MICROS 3600000000UL // 1 hour. 0 plays until stopped. Also the longest on and off ramp.

// Default settings, at startup and after a comm failure. The Python and MATLAB classes program the same ones.
#define DEFAULT_FREQUENCY_CENTIHZ 10000 // 100Hz
#define DEFAULT_AMPLITUDE_MICROVOLTS 5000000 // 5V peak to peak
#define DEFAULT_PLAY_DURATION_MICROS 1000000 // 1 second

// The sample clock. The sampling rate is samplesPerCycle times the frequency, where samplesPerCycle is the largest
// multiple of 4 that keeps the rate at or below MAX_SAMPLING_RATE: so a sample falls on every edge, peak and trough of
// every waveform (see "How playback works" in Playback.ino).
#define MAX_SAMPLING_RATE 100000 // Hz
#define TIMER_CLOCK_HZ 24000000 // The PIT timer behind IntervalTimer counts this clock
#define TIMER_TICKS_PER_SAMPLE_NUMERATOR 2400000000UL // TIMER_CLOCK_HZ * 100. Timer ticks per sample are this divided by
                                                      // (frequency in hundredths of a Hz * samplesPerCycle)
#define PLAYBACK_IRQ_PRIORITY 64 // Priority of the sample clock and trigger interrupts. Both must be equal, so that neither
                                 // interrupts the other in the middle of a DAC write. It is above the USB interrupt (128),
                                 // so a USB transfer cannot delay a sample.
static_assert((uint64_t)TIMER_CLOCK_HZ * 100 == TIMER_TICKS_PER_SAMPLE_NUMERATOR, "Ticks per sample numerator");
static_assert((uint64_t)MAX_FREQUENCY_CENTIHZ * 4 <= (uint64_t)MAX_SAMPLING_RATE * 100,
              "At the highest frequency, 4 samples per cycle must fit in the highest sampling rate");

// Timed DAC updates, see dacLoadTimed() in HardwareIO.ino. As in Pulse Pal 3 firmware (DAC_LATCH_US in
// /Firmware/PulsePal3/PulsePal3.ino), with the write times measured in Synth Pal's handler(): 1.38us for one channel
// and 4.67us for four, the longest of 60000 ticks each.
#define CPU_CYCLES_PER_US (F_CPU / 1000000) // DAC updates are timed in CPU cycles: see "The time base" in HardwareIO.ino
#define CPU_CYCLES_PER_TIMER_TICK (F_CPU / TIMER_CLOCK_HZ) // 25 at 600MHz
#define TICK_RESYNC_CYCLES 600 // tickCycles is set from the timer if they disagree by more than this (1us at 600MHz).
                               // At a clock start the PIT begins counting up to 259 cycles (measured) after
                               // startSampleClock() reads the cycle counter; a missed tick is ~6000 cycles off.
static_assert(F_CPU % TIMER_CLOCK_HZ == 0, "The CPU clock must be a whole multiple of the sample clock's timer clock");
#define DAC_WRITE_OVERHEAD_US 0.25 // Time to start writing, once per update
#define DAC_CHANNEL_WRITE_US 1.2 // SPI write of one DAC channel
#define DAC_LATCH_GAP_US 1.5 // Time from the last write to the latch. The DAC updates at once only some time after a write.
                             // handler() fetches the next samples in this time.
#define DAC_LATCH_US 7.5 // Outputs change this long after each tick of the sample clock: the interrupt's start (up to
                         // about 1us), the writes of 4 channels, and the gap
#define DAC_LATE_TOLERANCE_US 0.25 // An update whose writes end this much later than planned counts in lateUpdates
#define DAC_WRITE_TO_LATCH_NS 200 // Time from a write to the latch, for the writes outside the timed updates (dacWriteNow(),
                                  // ProgramDAC()). The DAC drops a write followed too soon by a latch: a channel keeps its
                                  // old output, and a control register write (e.g. power up) is lost. Measured on a Pulse
                                  // Pal 3, 30ns failed and 60ns worked. digitalWrite() alone, the delay in dacLatch(), is
                                  // shorter than that.

// The sine wave is read from a table of its first quarter cycle, with linear interpolation (see quarterSine() in
// Playback.ino). With 4096 steps the interpolation is within 2e-8 of the true sine, under a thousandth of a DAC code.
#define SINE_TABLE_SIZE 4096

// Screen saver, as in Pulse Pal firmware. Once the device has been left alone for screenSaverTimeout seconds (no command
// from the PC, no rising edge on a trigger channel, and no joystick click or push), it dims the screen. Any of these
// brings the screen back. Op 99 switches it on or off and sets the timeout; the joystick menu switches it on or off.
#define SCREEN_SAVER_DEFAULT_TIMEOUT 1800 // Seconds, until op 99 sets another
#define SCREEN_BRIGHTNESS 128 // Brightness of the oLED display (u8g2 contrast, 0-255). Use 128 max because:
                              // 1. Higher values can draw excess current from the USB supply. 2. To extend the lifetime of the display
#define SCREEN_SAVER_DIM_BRIGHTNESS 8 // Brightness while the screen saver dims the screen

// EEPROM layout. These are Pulse Pal firmware's addresses (/Firmware/PulsePal3/PulsePal3.ino), so the calibration and
// the screen saver settings carry over when a device changes firmware.
#define EEPROM_ZERO_CODE_CALIBRATION_ADDRESS 0 // ZeroCodeCalibration (int16 x 4), set by Pulse Pal firmware's op 96
#define EEPROM_SCREEN_SAVER_ADDRESS 16 // screenSaverEnabled (byte), then screenSaverTimeout (uint16)

#define TriggerLevel 0  // Trigger line level when the trigger is active. The optoisolators are inverting: their output is
                        // high by default, and goes low when voltage is applied to the trigger channel.

// --- Pin map, to define connections of IC pins (as in Pulse Pal 3 firmware) ---
#define CS 17
#define DC 37
#define RST 16
constexpr byte TriggerLines[2] = {2, 3}; // Trigger channels 1 and 2
constexpr byte InputLEDLines[2] = {1, 4}; // LEDs above trigger channels 1-2
constexpr byte ClickerXLine = 41; // Analog line that reports the thumb joystick x axis
constexpr byte ClickerYLine = 40; // Analog line that reports the thumb joystick y axis
constexpr byte dacMap[4] = {3, 2, 0, 1}; // Mapping of DAC output pins to output BNC connectors from left to right
#if (PIN_MAP_VERSION == 0) // PP3 PCB v 3.0.4 and older
  constexpr byte OutputLEDLines[4] = {24, 28, 29, 30}; // LEDs above output channels 1-4
  constexpr byte ClickerButtonLine = 34; // Digital line that reports the thumb joystick click state
  constexpr byte SyncPin = 14; // AD5754R Pin 7 (Sync)
  constexpr byte LDACPin = 39; // AD5754R Pin 10 (LDAC)
#else // PP3 PCB v 3.0.5 and newer
  constexpr byte OutputLEDLines[4] = {24, 32, 33, 35};
  constexpr byte ClickerButtonLine = 36;
  constexpr byte SyncPin = 34;
  constexpr byte LDACPin = 28;
#endif

// Hardware objects
ArCOM PPUSB(Serial); // ArCOM USB serial wrapper. The name is kept from Pulse Pal firmware, so that ArCOM.h is shared.
// 2ND in the constructor name selects the second SPI bus, checked for above with U8X8_HAVE_2ND_HW_SPI
U8G2_SSD1322_NHD_128X64_F_2ND_4W_HW_SPI u8g2(U8G2_R0, CS, DC, RST);
LiquidCrystal_U8G2 lcd(u8g2);
IntervalTimer hardwareTimer; // Attaches handler() to the PIT timer interrupt. The firmware then starts, stops and loads the
                             // timer's PIT channel itself (see startSampleClock() in HardwareIO.ino).
IMXRT_PIT_CHANNEL_t *sampleClockChannel = nullptr; // The PIT channel hardwareTimer took, found in setup()
SPISettings DACSettings(30000000, MSBFIRST, SPI_MODE2); // The AD5754R's maximum SPI clock is 30MHz

// ---------------------------------------------------------------------------------------------------------------
// Settings. Programmed from USB and the joystick menu. See PROTOCOL.md and Settings.ino.
// ---------------------------------------------------------------------------------------------------------------
uint32_t frequencyCentiHz = DEFAULT_FREQUENCY_CENTIHZ; // Frequency of all output channels, in hundredths of a Hz
byte waveform[N_CHANNELS] = {0}; // See enum WaveformValue
int32_t amplitudeMicrovolts[N_CHANNELS] = {0}; // Peak to peak (0 or more), or the voltage of WAVEFORM_FIXED_VOLTAGE
int32_t restingVoltageMicrovolts[N_CHANNELS] = {0}; // The output while the channel is idle
int32_t meanVoltageMicrovolts[N_CHANNELS] = {0}; // A periodic waveform's mean, while it plays at full amplitude
uint32_t playDurationMicros[N_CHANNELS] = {0}; // How long the channel plays at full amplitude after its on ramp. 0 = until
                                               // stopped.
uint32_t onRampMicros[N_CHANNELS] = {0}; // How long the channel fades in after each trigger. 0 = no on ramp.
uint32_t offRampMicros[N_CHANNELS] = {0}; // How long the channel fades out when it stops. 0 = no off ramp.
volatile byte TriggerAddress[2][N_CHANNELS] = {0}; // Output channels triggered by trigger channel 1 (row 1) and 2 (row 2)
volatile byte TriggerMode[2] = {0}; // One per trigger channel. See enum TriggerModeValue
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
void loop() {
  takeSyncedSettings(); // Settings that output channels took at a param sync edge, before a command can change them
  processUSBCommands(); // Read and execute a command from the PC, if one is available
  PPUSB.flush(); // Send any reply from this pass as a single USB packet
  updateScreenSaver(); // After the reply is sent, so that waking the screen never delays it
  takePendingOutputIfIdle(); // Settings that handler() had no time to take before the last channel stopped
  UpdateMenu();
  if (PPUSB.timedOut()) { // A serial USB message started, but didn't finish as expected
    HandleReadTimeout();
  }
}

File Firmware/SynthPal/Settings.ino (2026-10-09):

/*
----------------------------------------------------------------------------

This file is part of the Pulse Pal Project
Copyright (C) 2026 Sanworks LLC, Rochester, NY, USA

----------------------------------------------------------------------------

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
*/


// The frequency and the output channel settings: their limits, each channel's output range, and handing new settings
// to the playback interrupts. The USB ops (USBOps.ino) and the joystick menu (Menu.ino) both change settings through
// the functions here, from loop().
//
// Functions in this file:
//   samplesPerCycleFor()
//   durationToSamples()
//   rampReciprocal()
//   durationsInSamples()
//   applyFrequency()
//   setFrequency()
//   setPlayDurations()
//   setRampDurations()
//   isValidOutputLevel()
//   fitAmplitude()
//   outputRangeFor()
//   exactCode()
//   nearestCode()
//   channelOutputFor()
//   updateChannelOutput()
//   takePendingOutputIfIdle()
//   paramSyncEnabled()
//   updateParamSyncPending()
//   isValidSettingsSet()
//   applySettings()
//   storeSettings()
//   takeSyncedSettings()
//   LoadDefaultSettings()
//
// OUTPUT RANGES
// Each channel's periodic waveform (or white noise) spans its mean voltage plus and minus half its amplitude, which
// must stay within +/-10V (isValidOutputLevel()). A fixed voltage (WAVEFORM_FIXED_VOLTAGE) is its amplitude, which is a
// voltage in its own right, -10V to 10V, and ignores the mean voltage. The resting voltage, which the channel outputs
// while idle, may be anywhere within +/-10V, and the ramps lead in straight lines from it to the waveform and back. So
// the channel's output stays within the span of its resting voltage and its waveform, and its output range is the one
// with the finest steps that holds that span (outputRangeFor()): 0-5V (76uV steps), then 0-10V or +/-5V (153uV), then
// +/-10V (305uV). The DAC has one output range register per channel, so the channels' ranges are independent.
// A new waveform, amplitude, mean or resting voltage is worked out into a ChannelOutput (updateChannelOutput()) and handed to
// handler(), which takes it on a tick, after that tick's DAC update (takePendingOutput() in Playback.ino). While the
// sample clock is stopped, loop() takes it at once. If the range changes, the DAC needs a range write as well as a
// code write, so the channel's output shows its old code in the new range for a fraction of a microsecond, as the
// range changes. A playing channel whose range does not change has no glitch: its next sample simply follows the new
// settings.

// The number of samples in one cycle at a frequency (in centiHz): the largest multiple of 4 that keeps the sampling rate
// at or below MAX_SAMPLING_RATE. 100000 at 1Hz, 332 at 300Hz, 4 at 20kHz.
uint32_t samplesPerCycleFor(uint32_t centiHz) {
  return 4 * (((uint32_t)MAX_SAMPLING_RATE * 25) / centiHz); // 25 = 100 centiHz per Hz / 4 samples
}

// A play duration in samples, at a sampling rate in centiHz (ditherDenominator). 0 (until stopped) stays 0, and any
// other duration lasts at least one sample.
uint32_t durationToSamples(uint32_t micros, uint32_t samplingRateCentiHz) {
  if (micros == 0) {
    return 0;
  }
  uint64_t samples = (((uint64_t)micros * samplingRateCentiHz) + 50000000ULL) / 100000000ULL; // Rounded
  return (samples == 0) ? 1 : (uint32_t)samples;
}

// The reciprocal of a ramp's length in samples, which the envelope is worked out with (fetchNextSample()). 0 for no ramp.
float rampReciprocal(uint32_t samples) {
  return (samples == 0) ? 0.0f : (1.0f / (float)samples);
}

// Each channel's play duration and ramps (from the settings arrays) in samples, at a sampling rate in centiHz
void durationsInSamples(uint32_t samplingRateCentiHz, uint32_t *durations, uint32_t *onRamps, uint32_t *offRamps) {
  for (byte i = 0; i < N_CHANNELS; i++) {
    durations[i] = durationToSamples(playDurationMicros[i], samplingRateCentiHz);
    onRamps[i] = durationToSamples(onRampMicros[i], samplingRateCentiHz);
    offRamps[i] = durationToSamples(offRampMicros[i], samplingRateCentiHz);
  }
}
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

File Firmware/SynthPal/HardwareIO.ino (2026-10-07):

/*
----------------------------------------------------------------------------

This file is part of the Pulse Pal Project
Copyright (C) 2026 Sanworks LLC, Rochester, NY, USA

----------------------------------------------------------------------------

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
*/


// Low level hardware access: DAC writes, output ranges, the sample clock's timer and software reset.
//
// Every function here that talks to the DAC uses the SPI bus, so after setup() it may only run in the playback
// interrupts, or in loop() with interrupts disabled. See "Interrupt rules" in Playback.ino.
//
// Functions in this file:
//   clampU16()
//   writeDACRegister()
//   dacLoad()
//   dacLatch()
//   cyclesSinceTick()
//   waitForCyclesSinceTick()
//   dacLoadTimed()
//   dacLatchTimed()
//   dacWriteTimed()
//   dacWriteNow()
//   dacSwitchRange()
//   ProgramDAC()
//   nextSamplePeriodTicks()
//   startSampleClock()
//   advanceSampleClock()
//   stopSampleClock()
//   Software_Reset()

static inline uint16_t clampU16(uint16_t value, int16_t offset)
{
    int32_t corrected = (int32_t)value + offset;

    if (corrected < 0) {
        return 0;
    }

    if (corrected > UINT16_MAX) {
        return UINT16_MAX;
    }

    return (uint16_t)corrected;
}

// Writes one channel's input register. The output changes on the next falling edge of LDAC, which the caller has set
// high.
static inline void writeDACRegister(byte channel, uint16_t value) {
  value = clampU16(value, activeCalibration[channel]);
  digitalWriteFast(SyncPin, LOW);
  dacBuffer[0] = dacMap[channel];
  dacBuffer[1] = value >> 8;
  dacBuffer[2] = value & 0xFF;
  SPI.transfer(dacBuffer, 3);
  digitalWriteFast(SyncPin, HIGH);
}

// Writes the channels whose DACFlags are set into the DAC's input registers. LDAC is left high, so the outputs keep their
// voltages until dacLatch() updates them all at once.
static inline void dacLoad() {
  digitalWriteFast(LDACPin, HIGH);
  for (byte i = 0; i < N_CHANNELS; i++) {
    if (DACFlags[i]) {
      writeDACRegister(i, dacValue[i]);
      dacOutput[i] = dacValue[i];
      DACFlags[i] = 0;
    }
  }
}

// Updates every output to the value last written for it, together, on the falling edge of LDAC
static inline void dacLatch() {
  digitalWrite(LDACPin, HIGH); // Teensy 4.1 is too fast! Wait for DAC register to update
  digitalWriteFast(LDACPin, LOW);
}

// CPU cycles since the tick that began the current sample period. See "The time base" above startSampleClock().
static inline uint32_t cyclesSinceTick() {
  return ARM_DWT_CYCCNT - tickCycles;
}

// Waits until the CPU's cycle counter is cycles past the tick that began the current sample period
static inline void waitForCyclesSinceTick(uint32_t cycles) {
  while (cyclesSinceTick() < cycles) {}
}

static const uint32_t DAC_LATCH_CYCLES = DAC_LATCH_US * CPU_CYCLES_PER_US;
static const uint32_t DAC_WRITE_OVERHEAD_CYCLES = DAC_WRITE_OVERHEAD_US * CPU_CYCLES_PER_US;
static const uint32_t DAC_CHANNEL_WRITE_CYCLES = DAC_CHANNEL_WRITE_US * CPU_CYCLES_PER_US;
static const uint32_t DAC_LATCH_GAP_CYCLES = DAC_LATCH_GAP_US * CPU_CYCLES_PER_US;
static const uint32_t DAC_LATE_CYCLES = (DAC_LATCH_US - DAC_LATCH_GAP_US + DAC_LATE_TOLERANCE_US) * CPU_CYCLES_PER_US;
static_assert(DAC_LATCH_US >= DAC_WRITE_OVERHEAD_US + (4 * DAC_CHANNEL_WRITE_US) + DAC_LATCH_GAP_US,
              "DAC_LATCH_US must allow 4 channel writes and the gap");
static_assert(DAC_LATCH_US * MAX_SAMPLING_RATE < 1000000, "The DAC update must come within the shortest sample period");

// The sample clock's DAC update, in two steps: dacLoadTimed() writes, then dacLatchTimed() updates the outputs, and
// handler() fetches the next samples in between. dacWriteTimed() does both.
// As Pulse Pal firmware's dacWriteTimed() (see rule 1 in /Firmware/PulsePal3/AGENTS.md), the channels whose code changes
// are written, and all outputs are updated together at DAC_LATCH_US after the tick, however many channels were written.
// The DAC updates every output when LDAC falls after the last write, so writing and latching at once would make the
// update time depend on how many channels changed (1.2us per channel): a square wave's edges would move as other
// channels' codes repeated or changed. Waiting also absorbs a late start of the interrupt.
// dacLoadTimed() waits before writing, so that the writes end just before the latch: SPI activity shows on the outputs
// as a few mV of digital feedthrough, and next to the update it is hidden in it. The writes end DAC_LATCH_GAP_US before
// the latch: the DAC updates at once only some time after a write, and a sooner latch takes effect late. Writes that
// end more than DAC_LATE_TOLERANCE_US later than that, or a latch that comes after DAC_LATCH_US, count in lateUpdates.
// Returns the number of channels written.
static boolean dacWritesEndedLate = false; // Set by dacLoadTimed() for dacLatchTimed()
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

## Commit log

2016-03-03 Fixed screen saver timing in v1.1 firmware
    [PulsePal_1_1.pde]
2016-03-28 Added support for Pulse Pal 2 on Python When settings are loaded from SD card using a software command, the settings are now read back from the device and pushed to MATLAB and Python parameter fields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
    [PulsePal.py, PulsePalExample.py, PulsePal_2_0_0.ino]
2016-04-16 Added C++ support for Pulse Pal 2 Added PCB design files for Pulse Pal 1.1 and 2 Added drivers for Pulse Pal 2 Added microSD file delete option in MATLAB for Pulse Pal 2 Fixed a bug in new trigger sy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
    [PulsePalSMT_Rev_0_5.brd, PulsePalSMT_Rev_0_5.sch, Rev1_0.brd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]
2016-04-19 -Added support for deleting microSD settings files from thumb joystick menu -Added more comments to Pulse Pal 2 firmware -Increased custom pulse limit to 5000 for Pulse Pal 2 -Renamed SetContinuousLo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
    [PulsePal_2_0_0.ino]
2016-04-19 -Restored functionality to thumb joystick "single pulse" option -Corrected default parameters in MATLAB client to match firmware
    [PulsePal_2_0_0.ino]
2016-04-22 -Added more code comments -Bug fix: Digit-wise voltage adjustment from thumb menu fixed to account for -0, restoring access to the range -1V to 0V -Bug fix: Added flag for DAC update when setting res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
    [PulsePal_2_0_0.ino]
2016-06-14 Firmware update - changed boot sequence to set DAC outputs to resting voltage immediately on power-up. Previous firmware versions had taken ~1ms to do so. This firmware version takes 10 microseconds 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
2016-09-30 Fixed voltage conversion in ProgramPulsePalParam for Pulse Pal 2
2017-05-05 -Fixed behavior of "pulse gated" mode when used with both trigger channels simultaneously -Updated firmware to use union for integer type conversion and SPI array writes for efficiency (frees CPU for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
    [PulsePal.py]
2017-06-22 bug fix in voltage output function "setFixedVoltage" (for Pulse Pal 2)
    Corrected the order of two Bytes in message containing voltage value.
    Tested on Pulse Pal 2 in firmware version 20
2017-10-18 -Added updated Pulse Pal 2 PCB design
    [PulsePalSMT_Rev_0_8.brd, PulsePalSMT_Rev_0_8.sch]
2023-09-27 -Python3: in sendCustomPulseTrain() and sendCustomWaveform() methods, added support for times and voltages given as numpy nd-array -Python3: Fixed a typo in the example code
    [PulsePal.py, PulsePalExample.py]
2023-11-03 -Fixed repo issue#2, Rounding of numbers (Phase1Duration). Thanks to Christian Skoven for pointing it out! -Python: Reformatted PulsePalObject class and added docstrings to improve clarity -Python: U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
    [ArCOM.py, PulsePal.py, PulsePalExample.py]
2024-02-07 -Python3: Added set2DefaultParams(), a method to return Pulse Pal to the default parameters initially set on initializing a PulsePal object. -Fixed case typo in example code
    [PulsePal.py, PulsePalExample.py]
2025-07-18 -Added Pulse Pal firmware v3 (likely very buggy)
    [PulsePal_3_0_0.ino]
2025-07-18 -Firmware: Fixed microSD support and software reset functions on hardware v3
    [PulsePal_3_0_0.ino]
2025-07-18 -Firmware: Fixed text centering and cursor behavior on hardware v3
    [PulsePal_3_0_0.ino]
2025-08-28 -Firmware: Fixed oLED current draw issue on Pulse Pal 3 -Firmware: Fixed screen-clearing on each thumb joystick nav event -Firmware: Added Sanworks logo
    [PulsePal_3_0_0.ino]
2025-11-06 - Firmware: Added improved data transfer methods - Firmware: Added macro for max custom pulse limit (HW dependent) - Firmware: Routed USB Serial via ArCOM - MATLAB software: Added a new class to inte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
2025-11-07 -Firmware: Fixed timer callback interference with main-loop USB data transfer. USB op menu is now called from main loop. -Firmware: Minor optimizations to ArCOM
    [PulsePal_3_0_0.ino]
2025-11-07 -Firmware: Removed CycleDuration variable, redundant with TIMER_PERIOD macro. CycleFrequency is now calculated from Timer_PERIOD. -Firmware: Added additional hardware info returned from op 94 - MATLA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
2025-11-07 -Firmware: Fixed limit on range of custom train ID
    [PulsePal_3_0_0.ino]
2025-12-04 -Firmware: Fixed op 78 (display text to screen) -MATLAB interface (legacy): Fixed EndPulsePal, added hardware information request to init process if new firmware detected
    [PulsePal_3.ino]
2026-06-01 -MATLAB GUI: Added function to sync GUI parameters and custom trains to device
2026-06-05 - Added DAC Zero-code error calibration to firmware and MATLAB software. Calibration is stored in EEPROM. - Firmware: Fixed a bug where ch4 would not always update due to timing of LDAC on hardware v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
    [PulsePal_3.ino]
2026-06-09 -Firmware: Added device info screen to menu, which displays hardware and firmware versions
2026-06-11 -Added Pulse Pal 3 CAD files for PCB and enclosure -Reorganized MATLAB folder to ensure that legacy interface is clearly noted as such -Firmware: Fixes to compile for Pulse Pal 2
    [PulsePal3 Assembly v1_0.f3d, PulsePal3 Body v1_0.stl, PulsePal3 ScreenMount v1_0.stl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]
2026-06-11 -Firmware: Fixed bug where first pulse triggered from thumb joystick menu could be up to 50us too short. Bug did not affect playback when triggered from TTL or API. -Firmware: Joystick menu playback 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
    [PulsePal_3.ino]
2026-06-11 -Firmware: Fixed type declaration
    [PulsePal_3.ino]
2026-06-19 -Firmware: Fixed bug re: filenames
    [PulsePal_3.ino]
2026-06-25 -Python: Added methods to sync parameters from device, load/save/delete microSD settings and format the microSD card -Python: Updated trigger_outputs() to accept a single channel or lists of channels
2026-06-25 -Firmware: Reset joystick menu level when connecting to app
    [PulsePal_3.ino]
2026-06-26 -Python: Added calibration method -Python: Added close op to exit and del functions -MATLAB: Renamed calibration method
2026-08-17 -Python: Improved compliance with pep8 -Firmware: Fixed bug where full sync to device op would not automatically update resting voltages
    [PulsePal.py, PulsePal_3.ino]
2026-08-17 -Python: Added GUI Dark mode -Python: Fixed bug where GUI window rendered under other windows on first launch
    [PulsePal.py, PulsePalGUI.py]
2026-08-21 -Python docs: Corrections and improvements
    [PulsePal.py]
2026-09-04 -Firmware: Setting continuous mode to 'on' no longer triggers the channel -MATLAB: playbackMode (normal vs. continuous) is synced with other output channel parameters -Python: Added playback_mode as 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
    [PulsePal.py, PulsePal_3.ino]
2026-09-04 -Python: Comment format fix for docs
    [PulsePal.py]
2026-09-07 -CAD: Updated PCB Design -MATLAB: Updated firmware binaries
    [PulsePal_3_0_1.brd, PulsePal_3_0_1.sch, PulsePal_3_0_4.sch]
2026-09-07 -Python GUI: Fixes for Ubuntu
    [PulsePalGUI.py]
2026-09-07 -Python GUI: Layout fixes
    [PulsePalGUI.py]
2026-09-07 -Python GUI: Fixes for layout on Ubuntu
    [PulsePalGUI.py]
2026-09-07 -Python GUI: Fixed load/save starting folder on Ubuntu
    [PulsePalGUI.py]
2026-09-07 -Python GUI: Fixed a bug where custom train data entered manually was not captured if another train was immediately selected
    [PulsePalGUI.py]
2026-09-17 -Firmware: Bug fixes - op 97 switch/case fallthrough, microSD file name truncation, confirm byte for op 90 and correct data management for custom trains 3 and 4
    [PulsePal_3.ino]
2026-09-17 -Python: Added efficient multi-channel support to set_output_param() -Python: Fixed order of parameters (and a related bug resulting in the wrong op code for resting_voltage) -Python: Restored suppor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
    [HardwareIO.ino, Menu.ino, Playback.ino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]
2026-09-17 -Firmware: Fixed bug where terminating a pulse train by thumb joystick could freeze the device -Firmware: Improved USB command sanitizing and out-of-bounds handling -Firmware: Retired PulsePal_2 -Fir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
    [Display.ino, HardwareIO.ino, Menu.ino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]
2026-09-17 -Firmware: Minor fixes to string handling and voltage range clamping
    [Display.ino, Menu.ino, Playback.ino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]
2026-09-23 -Added a new trigger channel mode (Pulse Pal v3 only): Param Sync. In Param sync mode, programming parameters with op 92 is deferred until a rising edge on the trigger channel. This enables sending t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
2026-09-23 -Firmware: Fixed a bug where full-capacity custom waveform would not loop -MATLAB and Python: Added a check for increasing custom pulse train onset times
    [Playback.ino, PulsePal.py]
2026-09-24 -Added WavePal firmware, MATLAB and Python classes, tests and documentation. WavePal plays longer sampled waveforms on trigger at sampling rates up to 100kHz. -Firmware: Tweaked splash screen -MATLAB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
2026-09-24 -Firmware: Commander string variable fix
    [PulsePal3.ino]
2026-09-29 -Firmware: Fixed a bug where USB triggers send during playback would cue and begin a new pulse train after playback finishes. USB triggers during playback are now ignored. -Firmware: Fixed a bug wher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
    [HardwareIO.ino, Playback.ino, PulsePal.py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]
2026-09-29 -MATLAB and Python: Improved handling of invalid inputs, fixed rounding for consistent behavior across interfaces
    [PulsePal.py]
2026-09-29 -MATLAB: Switched to .NET serial interface when available on Windows for significantly improved latency
2026-09-30 -Firmware: Biphasic pulses are now played only if they fully fit in the pulse train -Firmware: Joystick menu enforces the 100us minimum pulse width -Firmware: Fixed USB transfers delaying playback on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
    [HardwareIO.ino, Menu.ino, Playback.ino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]
2026-10-07 -SynthPal: Fixed an issue with playback stop
    [Playback.ino, SynthPal.ino]
2026-10-07 -WavePal and SynthPal: Fixed DAC latch timing
    [HardwareIO.ino, SynthPal.ino, WavePal.ino]
2026-10-07 -SynthPal: Added Fixed Voltage waveform -SynthPal: Menu fixes
    [Menu.ino, Playback.ino, Settings.ino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]
2026-10-08 -Python: pulsepal package; settings program the device at once (batch(), auto_sync); trigger() takes channel numbers; names instead of codes; continuous_loop; set_fixed_voltage; one PulsePalError -MA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
    [Playback.ino, PulsePal.py, PulsePalExample.py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]
2026-10-09 -Firmware: Joystick menu times up to 9999.9999s -WavePal, SynthPal: Disconnecting (op 81) stops all channels, as on Pulse Pal -Python, MATLAB, C++: Matched value limits (9999.9999s, custom times in 1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
    [Menu.ino, PulsePal.h, PulsePal3.ino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]
2026-10-09 -Firmware: Wave Pal screen saver (op 99, joystick menu item, EEPROM settings shared with Pulse Pal and Synth Pal); Synth Pal op 82 ('R') reads every setting back; Wave Pal and Synth Pal hex files reb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
    [Display.ino, Menu.ino, Playback.ino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]
2026-10-09 -Firmware: Synth Pal White Noise waveform (code 5): a new random voltage on every sample, uniform over the peak to peak voltage around the mean voltage, at the sampling rate the frequency sets; one x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
    [Menu.ino, Playback.ino, Settings.ino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]
2026-10-11 -Firmware: Wave Pal stores four waveforms (1-4), each played by any output channels: op 76 takes a waveform number, and new op 67 ('C') sets each channel's current waveform (0 = none, the default); e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
2026-10-12 -Added function to read the PCB version number into each class's info field. Version number is set on the board as an array of grounded Teensy pins
2026-10-14 -Firmware: Fixed a channel left silent, or playing for ever, when bursts were switched off between two bursts -MATLAB: GUI keeps every line of a custom train box; refuses out-of-range values with a d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
2026-10-15 -Pulse Pal v2: Fixed an issue where polls from the latest version of Arduino IDE could freeze the board's USB interface
2026-10-18 -Firmware: Folder and main tab renamed from PulsePal3 to PulsePal, as WavePal and SynthPal; custom pulses and bursts play the voltage they started with (phase 2 and a burst's later pulses could read 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
2026-10-19 -Pulse Pal firmware: Set hardware timer priority above USB for improved timing precision
2026-10-19 -Firmware (for v3 only): DAC updates are timed from the CPU's cycle counter instead of by polling the hardware timer's counter, whose reads took about 0.1 us each. An output edge no longer moves by ~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
2026-10-20 -Firmware (for v3 only): 10 us cycle, down from 50us with the DAC latched by the timer (FlexPWM3) -Firmware: Op 103 handshake; older clients (op 72) and settings files keep 50 us times; ops 73, 74, 9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
2026-10-21 -Added hardware test for initial validation of new Pulse Pal 3 devices
2026-10-22 -Firmware (Pulse Pal 3 only): Optimized memory usage by switching from full sprintf to the integer-only version
2026-11-08 -CAD: Added Pulse Pal 3 BOM -Docs: Small fixes
2026-11-11 -Firmware: Fixed a race in which stopping a channel playing a custom train (ops 80, 81, 98), then loading the train once, made its next trigger end at once at its resting voltage; stops now run with 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
2026-11-11 -Updated docs to reflect new 3-repository scheme: PulsePal, PulsePal-CAD and PulsePal-Firmware

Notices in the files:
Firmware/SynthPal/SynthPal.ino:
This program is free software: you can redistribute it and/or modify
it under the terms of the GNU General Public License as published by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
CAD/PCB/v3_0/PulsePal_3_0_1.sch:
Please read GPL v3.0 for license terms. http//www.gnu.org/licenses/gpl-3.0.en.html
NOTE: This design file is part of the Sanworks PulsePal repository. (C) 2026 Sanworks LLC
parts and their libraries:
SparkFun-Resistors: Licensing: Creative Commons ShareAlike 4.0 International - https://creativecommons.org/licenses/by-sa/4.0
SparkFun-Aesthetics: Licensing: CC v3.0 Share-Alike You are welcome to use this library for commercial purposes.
